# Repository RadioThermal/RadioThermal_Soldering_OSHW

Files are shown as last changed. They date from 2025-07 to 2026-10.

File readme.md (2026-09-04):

RadioThermal 470KHz Induction Soldering Station - Open Source Hardware
========================

This repository contains the designs and resources to build a high-performance induction soldering iron at a relatively low cost. [Check out radiothermal.com for more information.](https://radiothermal.com/products.html)

### [Join our Discord server](https://discord.gg/hySrP3z9Kq)

### [Join our mailing list to get updates on this project](https://radiothermal.com/mailing.html)

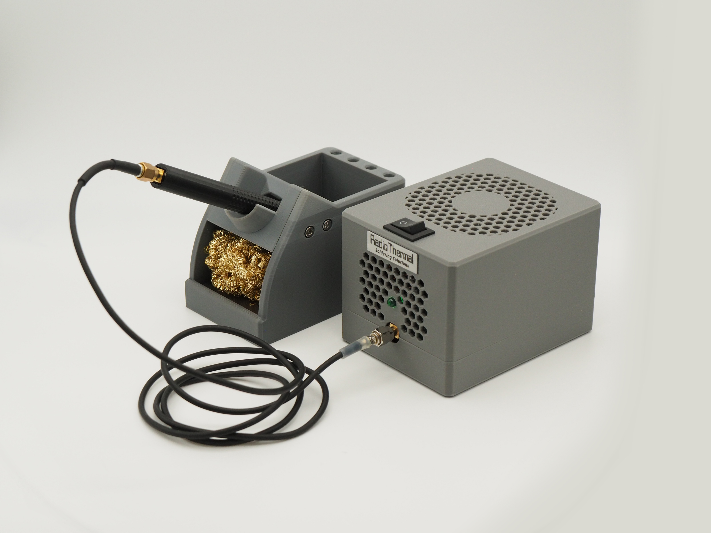
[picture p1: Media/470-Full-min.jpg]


The 470KHz soldering system is made up of four major components: the power supply, the handpiece, the cable, and the workstand. Follow the links to see the assembly instructions and files for each component.

### [Power Supply](https://github.com/RadioThermal/RadioThermal_Soldering_OSHW/tree/main/Power%20Supply)

The power supply is the core of the 470KHz system. It consists of a PCB design that includes a class-E amplifier and contains impedance matching circuitry to properly provide power to the soldering iron tip. 

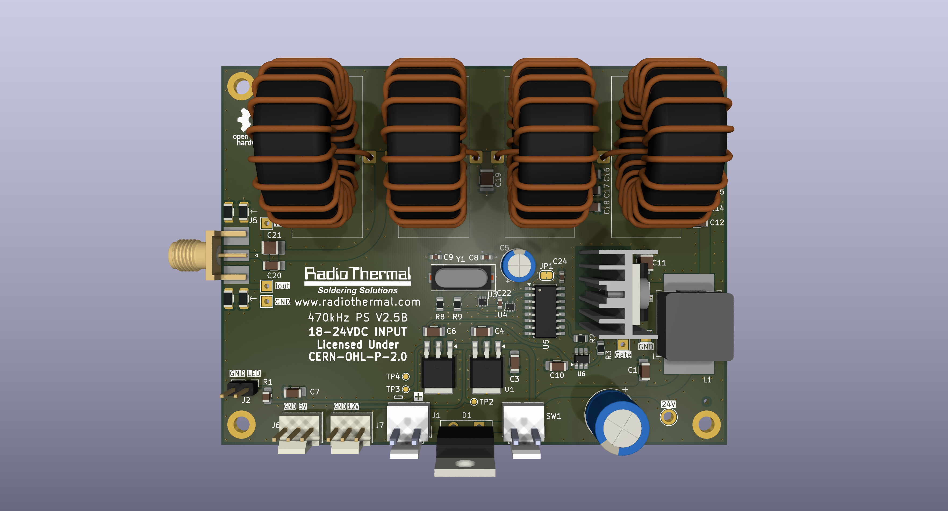
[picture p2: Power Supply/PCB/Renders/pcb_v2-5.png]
case


### [Handpiece](https://github.com/RadioThermal/RadioThermal_Soldering_OSHW/tree/main/Handpiece)

The handpiece is the primary user interface of the soldering system. It consists of a core built with brass tubing and an outer 3D printed grip for comfort during use.

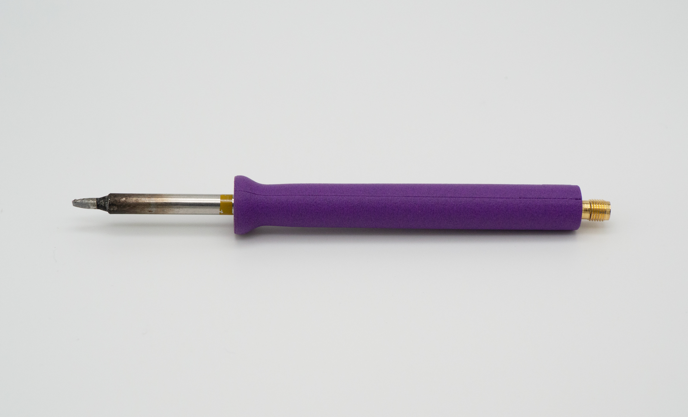
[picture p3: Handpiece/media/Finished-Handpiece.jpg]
hp


### [Cable](https://github.com/RadioThermal/RadioThermal_Soldering_OSHW/tree/main/Cable)

The cable is a specially modified RG-174 coaxial cable with SMA connectors on each end. A silicone jacket has been added for burn resistance, with additional silicone layers on each end for improved strain relief

### [Workstand](https://github.com/RadioThermal/RadioThermal_Soldering_OSHW/tree/main/Workstand)

The workstand is a primarly 3D printed part that gives the user a safe place to their hot soldering iron, along with brass wool to clean the tip. Magnets are used to cool down the soldering iron tip when not in use. The back of the stand contains storage for four tips.

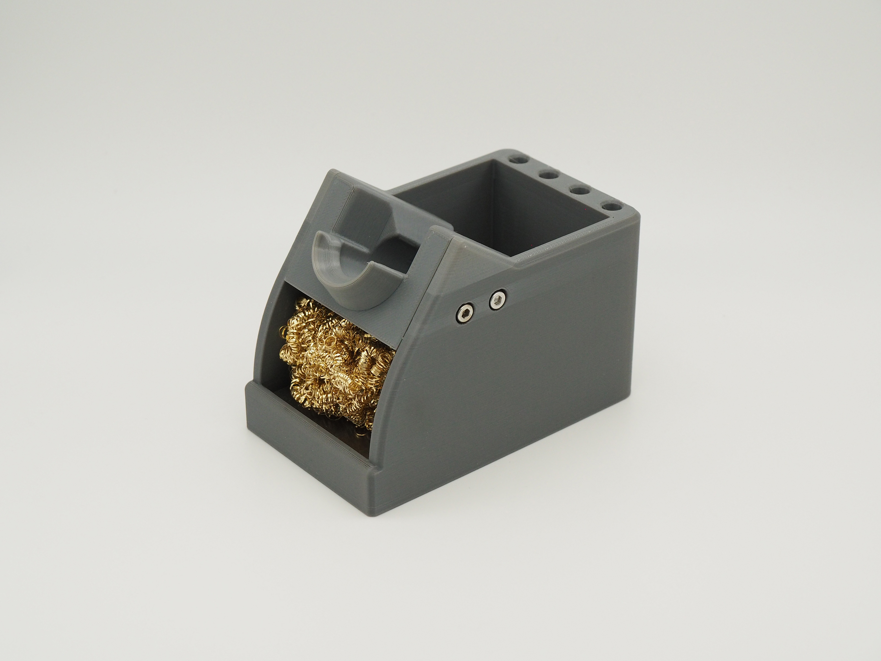
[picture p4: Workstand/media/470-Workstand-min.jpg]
ws


### [Extra - Compatibility Adapters](https://github.com/RadioThermal/RadioThermal_Soldering_OSHW/tree/main/Adapters)

We have designed compatibility adapters to allow our cable and handpiece to be used with preexisting 470KHz power supplies including Metcal PS, Metcal MFR, and Thermaltronics TMT-2000.

# Project Status

Here is an overview of the current state of completion for each major component of the project

| Component | Status |
| --- | --- |
| Power Supply | Updated to V2.5B |
| Handpiece | Complete |
| Cable | Complete |
| Workstand | Complete |
| Compatibility Adapters | Updated version coming soon |

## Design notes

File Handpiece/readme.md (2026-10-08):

# 470KHz Handpiece Assembly Instructions

#### 1. Gather materials

Prepare your materials for assembling the core of the handpiece. Links below go to where materials can be purchased.

| **Component** | **Quantity** | **Notes** |
| --- | --- | --- |
| Handpiece grip | 1 | 3D printed handpiece grip, in [3D Printed Grip folder](https://github.com/RadioThermal/RadioThermal_Soldering_OSHW/tree/main/Handpiece/3D%20Printed%20Grip) |
| [7/32" OD x 0.014" wall brass tube](https://ksmetals.com/products/round-brass-tube-7-32-od-x-0-014-wall-x-12-long-1-piece?) | 1 | Cut to 14mm length |
| [1/4" OD x 0.014" wall brass tube](https://ksmetals.com/products/br014-1-4?) | 1 | Cut to 70mm length |
| [Handpiece PCB](https://github.com/RadioThermal/RadioThermal_Soldering_OSHW/tree/main/Handpiece/Handpiece%20PCB) or Double sided copper clad FR4 board | 1 | For copper clad FR4 option, cut to 9x15mm rectangle |
| [Edge launch SMA connector](https://www.digikey.com/en/products/detail/samtec-inc/SMA-J-P-H-ST-EM1/2602450) | 1 | 7mm max width, straddle mount variety |
| [D-Sub female socket contact](https://www.digikey.com/en/products/detail/mh-connectors/MHDM-STF/16983882) | 1 | Solder cup variety, can be recycled from used connectors |
| 4.5mm OD x 8mm crown spring/socket contact | 1 | [Aliexpress](https://www.aliexpress.us/item/3256801561640843.html?) (contact seller for more size options), [TE Connectivity](https://www.te.com/en/product-6-192041-9.html), or [DigiKey](https://www.digikey.com/short/35073bvt) |
| 470KHz soldering iron tip | 1 | [Metcal/OKi STP/SFP/SCP series](https://store.metcal.com/en-us/shop/cartridges-tips/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) tips or [Thermaltronics P series](https://www.thermaltronics.com/p_series.php) tips |

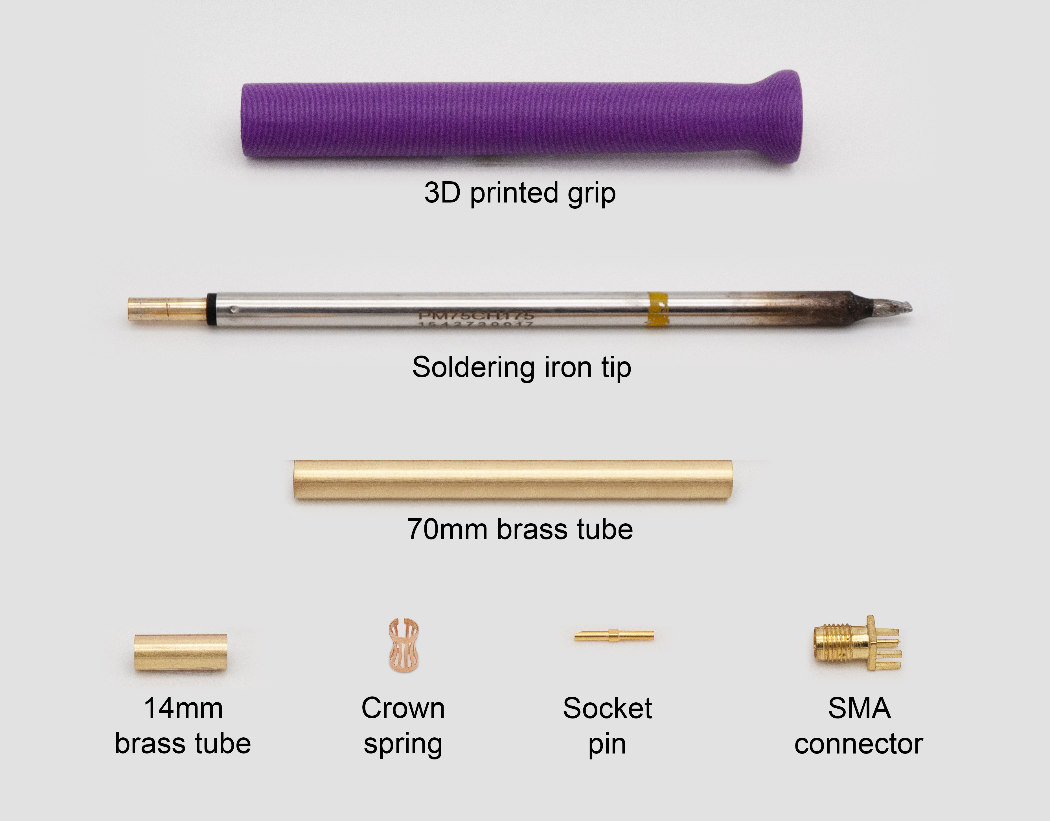
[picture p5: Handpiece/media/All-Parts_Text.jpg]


#### 2. Prepare circuit board

**Tools and components needed:**

If using premade [Handpiece PCB](https://github.com/RadioThermal/RadioThermal_Soldering_OSHW/tree/main/Handpiece/Handpiece%20PCB), skip to step 3

| Component | Quantity |
| --- | --- |
| Double sided copper clad FR4 board | 1 |

| Tool | Description/use |
| --- | --- |
| Hacksaw | Cutting FR4 |
| Vise or clamp | Holding FR4 during cutting |
| Calipers | Measuring FR4 |
| Narrow chisel | Cutting FR4 and scraping copper |
| Rectangular metal file | Flattening FR4 edges, cleaning up cuts |
| Fine point permanent marker | Marking FR4 for cutting and copper for scraping |

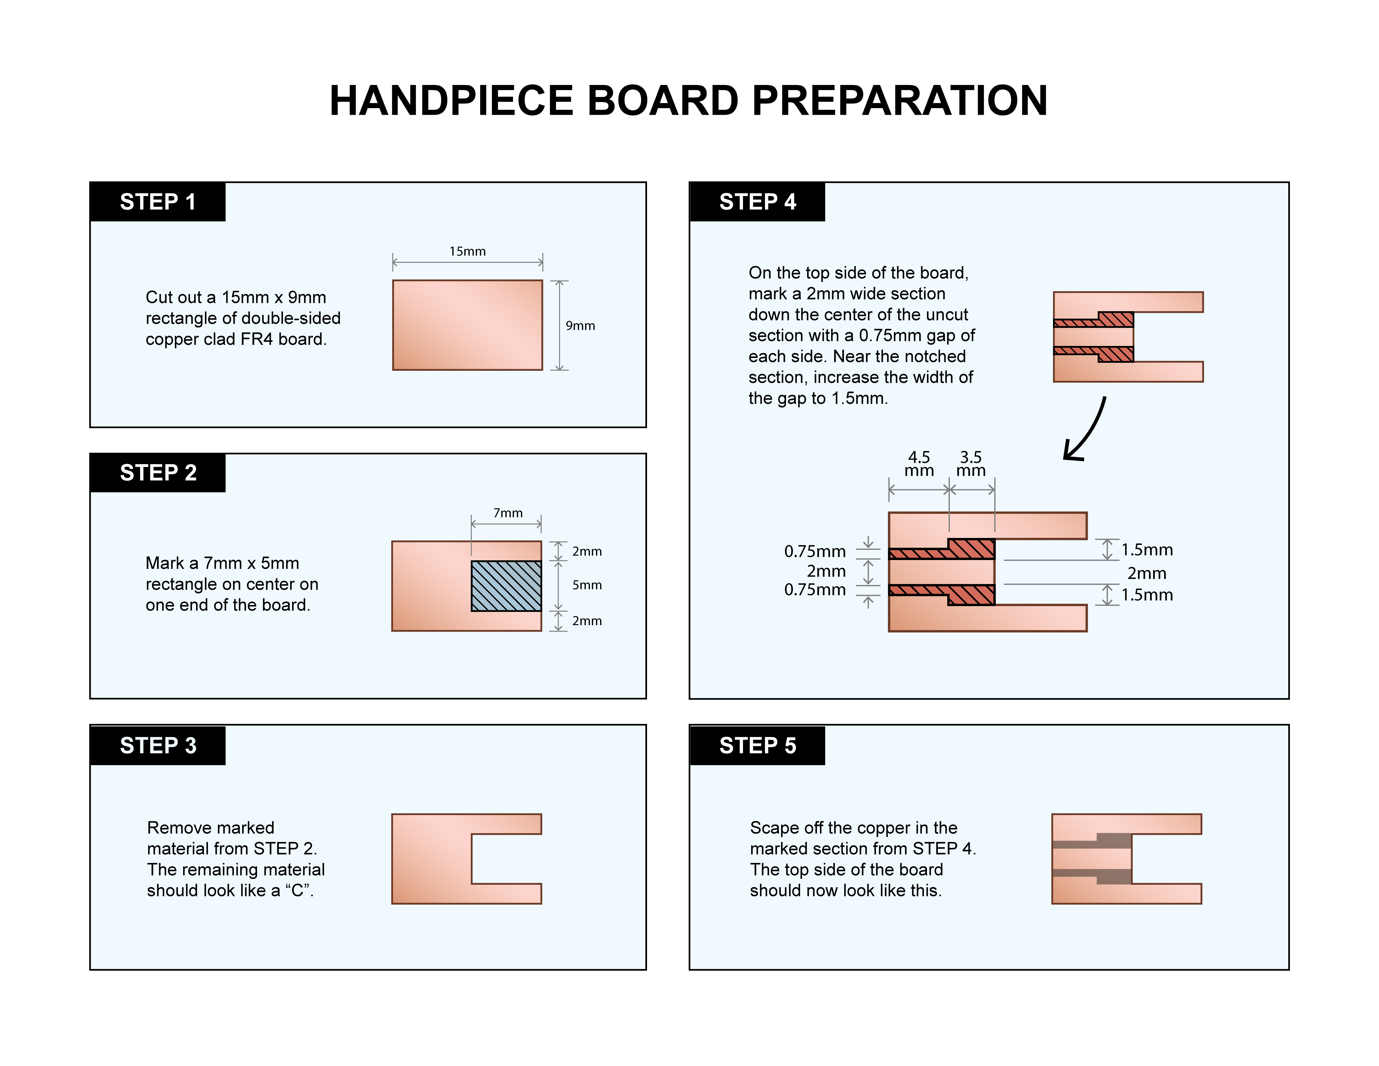
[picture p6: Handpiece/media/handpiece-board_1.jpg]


#### 3. Attach the SMA connector

**Tools and components needed:**

| Component | Quantity |
| --- | --- |
| Completed 9x15mm board with notch cut and copper removed | 1 |
| Edge launch SMA connector | 1 |

| Tool | Description/use |
| --- | --- |
| Soldering iron | Soldering SMA connector to board |
| Solder | 63/37 alloy is peferable, other leaded or lead free alloys may work |
| Flux | Liquid type is preferable |
| Needle nose pliers | Bending SMA connector legs |

Once the board has been completed, now it is time to attach the SMA connector. Position the connector so that the center contact touches the 2mm wide center strip on the board, while the outer legs do not touch the center strip. If the connector is a loose fit on the board, bend the outer legs together slightly so that it securely grasps the board. 

Apply soldering flux to all of the legs of the SMA connector. Starting from the outer legs, solder the connector to the board. When soldering the center pin, do not keep the soldering iron on the pin for an extended period of time, as it may damage the plastic insulator inside the connector. Once soldering of the SMA connector is complete, inspect and correct any solder bridges between the center pin and outer legs.



#### 4. Install crown spring into socket tube

**Tools and components needed:**

| Component | Quantity |
| --- | --- |
| 4.5x8mm crown spring | 1 |
| 7/32" OD x 0.014" wall brass tube, cut to 14mm | 1 |
| 470KHz soldering iron tip | 1 |

| Tool | Description/use |
| --- | --- |
| Soldering iron | Soldering crown spring into tube |
| Solder | 63/37 alloy is preferable, other leaded or lead free alloys may work |
| Flux | Liquid type is preferable |



Insert the crown spring into the 14mm piece of brass tubing, then partially insert the coaxial end of the soldering iron tip into the crown spring. Leave about half of the spring visible and ensure there is a 2mm space between the top of the spring and the end of the tubing.



Once the spring has been placed, apply a small amount of liquid soldering flux to the exposed end of the spring. Using a fine tip soldering iron, apply a small amount of solder to where the spring contacts the brass tube. Make sure the solder flows around the spring  to ensure that it says in place during use.

#### 5. Complete the socket assembly

**Tools and components needed:**

| Component | Quantity |
| --- | --- |
| Board with SMA connector from step 3 | 1 |
| 14mm socket tube with spring from step 4 | 1 |
| D-Sub female socket contact | 1 |
| 470KHz soldering iron tip | 1 |

| Tool | Description/use |
| --- | --- |
| Soldering iron | Soldering tube and socket pin to board |
| Solder | 63/37 alloy is preferable, other leaded or lead free alloys may work |
| Flux | Liquid type is preferable |



Begin by inserting the D-Sub female socket contact onto the center pin of the coaxial connector of the soldering iron tip. Verify that the contact is able to easily slide onto the center pin and grasps firmly enough to not fall off when turned upside down. If the contact is loose on the center pin, it may be necessary to squeeze the cut end slightly so that it firmly grasps the pin. Once the socket contact has been fully inserted, slide it approximately 2mm back off of the pin so that it can account for variances in soldering iron tip connectors.

Next, slide the 14mm socket tube all the way down on the outer ring of the coaxial connector on the soldering iron tip. The soldered end of the spring should be facing outwards.



Slide the notched section of the board all of the way onto the socket tube, and ensure the center pin is aligned with the 2mm copper strip.

Apply flux to the points of contact between the socket tube and the board. Solder the socket tube to the board. Make sure that the solder flows onto both the tubing and board, creating a strong bond. It is only necessary to solder on the top side of the board. Be careful not to keep the soldering iron on the board and tubing for an extended period of time. Excessive heat could cause the previously soldered components to lose their connection. Finally, solder the D-Sub female contact onto the 2mm strip on the board.



Now the socket assembly is complete. Clean off any remaining flux. Test the socket assembly using a multimeter in continuity mode with probes connected to the center pin and outside of the SMA connector. If no soldering iron tip is inserted, the connection will be open. If a tip is inserted, the connection will be shorted.



#### 6. Attach the support tube to the socket assembly

**Tools and components needed:**

| Component | Quantity |
| --- | --- |
| Socket assembly from step 5 | 1 |
| 11/4" OD x 0.014" wall brass tube, cut to 70mm | 1 |
| 470KHz soldering iron tip | 1 |

| Tool | Description/use |
| --- | --- |
| Soldering iron | Soldering tube and socket pin to board |
| Solder | 63/37 alloy is preferable, other leaded or lead free alloys may work |
| Flux | Liquid type is preferable |
| Isopropyl alcohol | Removing flux residue |



Slide the 70mm piece of tubing onto the coaxial connector end of the soldering iron tip. Ensure that the tube is slid past the end of the coaxial connector section of the tip. The tubing should be able to slide onto the tip very easily. If the tubing does not slide easily, replace your tubing.

Next, slide the socket assembly fully onto the coaxial connector of the soldering iron tip. Slide the 70mm tube back so that it is covering the first 3mm of the tube in the socket assembly. Use a piece of kapton tape to affix the 70mm tube to the soldering iron tip so that it does not move during the soldering process.

Apply soldering flux to the where the brass tubes contact. Apply a small amount of solder to the joint between the two tubes and rotate the workpiece so that the entirety of the joint between the brass tubes is soldered. Make sure that the solder flows onto both pieces of tubing, creating a strong bond. Finally, remove the kapton tape and soldering iron tip.

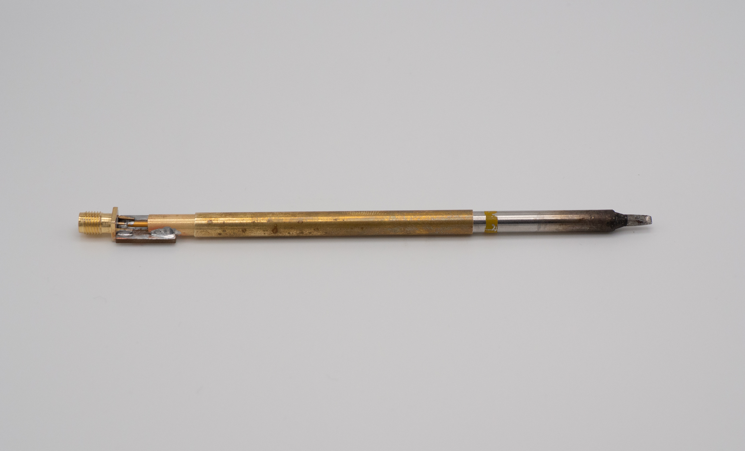
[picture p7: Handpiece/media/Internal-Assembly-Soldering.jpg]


The inner portion of the handpiece is complete. Clean off any remaining flux and thoroughly wash the inside of the tube with isopropyl alcohol or another solvent. Test the fit of the tip into the assembly. It should easily slide into the tube and firmly grasp once it reaches the socket. 



#### 7. Installing the handpiece grip

**Tools and components needed:**

| Component | Quantity |
| --- | --- |
| Handpiece innner assembly from step 6 | 1 |
| 3D printed handpiece grip | 1 |

| Tool | Description/use |
| --- | --- |
| 1/4" drill bit | Removing stringing and widening grip |



Inspect the 3D printed handpiece grip to verify that there is no stringing inside the hole. If stringing is present, use a 1/4" drill bit to clear the hole. Next, insert the inner assembly into the 3D printed grip. It should be a tight fit. If the inner assembly cannot be inserted, use a 1/4" drill bit to enlarge the hole. The inner assembly is fully inserted when only the SMA connector is protruding from the grip.

Now your 470KHz handpiece is complete!



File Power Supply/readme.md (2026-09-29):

# Power Supply

The power supply is the core of the 470KHz system. It is based upon a class-E amplifier and contains impedance matching circuitry to properly provide power to the soldering iron tip.

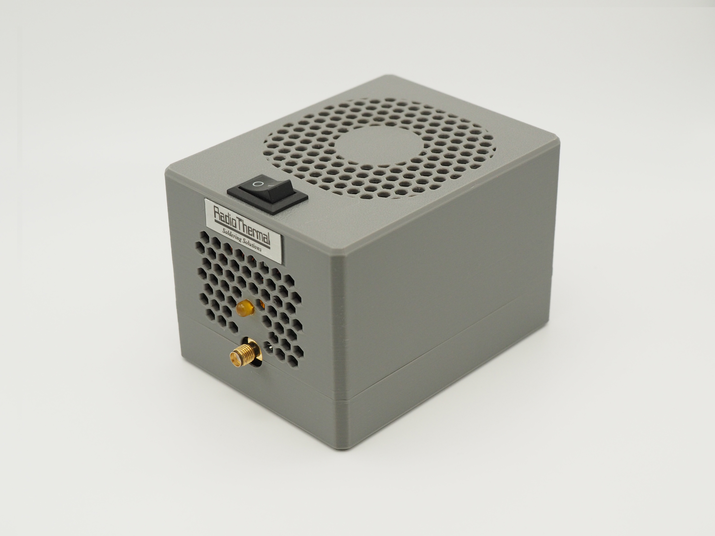
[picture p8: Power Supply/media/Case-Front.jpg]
(/media )


#### The PCB

The provided PCB design includes all basic functionality needed to operate a 470KHz soldering iron tip. 

The design includes provisions for inrush current limiting, reverse polarity protection, a cooling fan, and two different types of oscillators. The inductors, apart from the fixed 33uH inductor, are all based around the [Kool Mu 0077932A7 core](https://www.mag-inc.com/Media/Magnetics/Datasheets/0077932A7.pdf), which is currently only available from Digikey, though we are looking for alternatives. 

In version 2.5B of the PCB, we have made a few improvements to reduce cost and increase reliability compared with version 2.3B1. Most notably the oscillator section has been redesigned to eliminate the need for a microcontroller and now only relies on a 7.6MHz crystal oscillator and TTL logic. To reduce costs, we have eliminated the daughter board by moving everything onto the main board, additionally L2 has been updated to only use a single inductor core from the two cores required on previous versions. Moving all of this new hardware onto the main board has had the consequence of causing us to remove the TO-247 MOSFET option in favor of TO-220 to save space.



Components required to assemble the board can be found in the [Digikey list we maintain](https://www.digikey.com/en/mylists/list/PVYU6ZC8DQ) , please let us know if there is a stocking issue for a component so that we can find a suitable alternative.

**Special note:** if you are one of the few people with a **V2.5** non-B PCB, please replace the 74LVC1G14 with a [74LVC2G14](https://www.digikey.com/en/products/detail/nexperia-usa-inc/74LVC2G14GW-125/1231583)

#### External DC Power Supplies

For testing we have been using Chicony A15-180P1A 20V 180W power supplies, however any power supply in the 18-24V range with a 100W or higher rating will work. We recommend utilizing a laptop power supply since they can be found on the used market at reasonable prices. Alternatively, a USB-C PD trigger board can be used in conjunction with a USB PD power supply that supports 20V 5A output.

#### The Case

The case design adds additional functionality to the PCB including a barrel jack for power input, a convenient power switch, power indicator LED, cooling fan, and a ground connection point. The airflow paths of the case have been optimized to exhaust out the front and back with the intake on top, keeping all of the inductors cool.

a

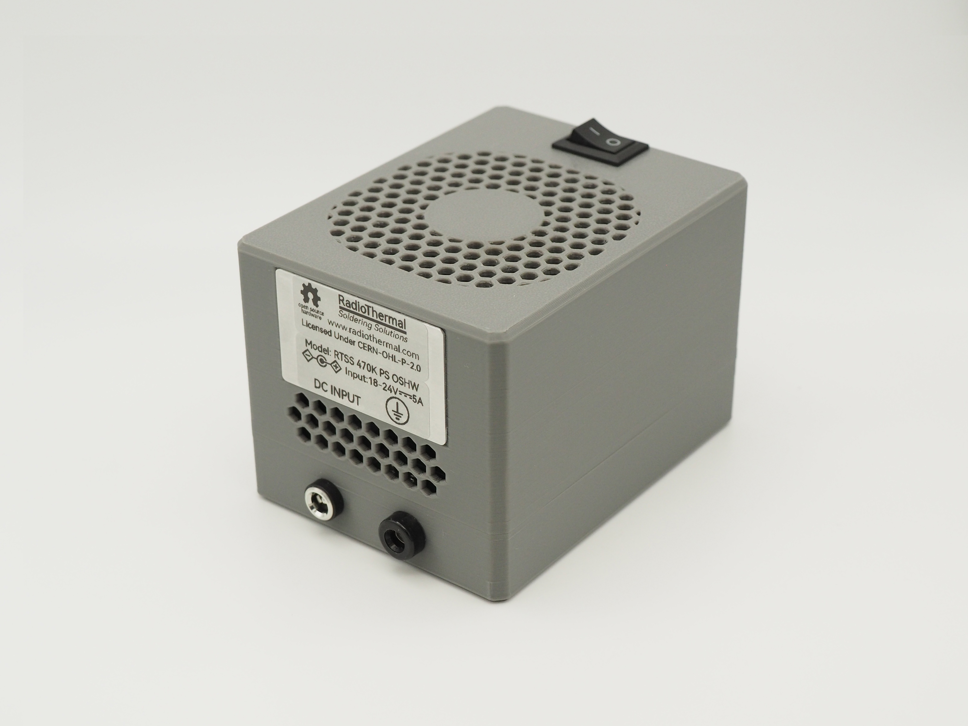
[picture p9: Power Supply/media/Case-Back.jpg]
case


The electronics parts and fasteners for the case [can be purchased from Digikey](https://www.digikey.com/en/mylists/list/RQ7FUDUM3L). 

The case fan mounts are only designed to support Delta AFB0712 series fans at present, other 70mm fans can be used by removing the fan mounting posts and gluing the four corners of the fan in place.

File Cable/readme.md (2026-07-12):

# Cable Assembly Instructions

#### 1. Gather materials

Prepare the following materials to assemble the cable

| **Component** | **Quantity** | **notes** |
| --- | --- | --- |
| RG174 coaxial cable | 1 | Cut to 1-2m length, depending on how long ou want your cable to be. For best results, use a cable with a tight braid and high flexibility. MUST have a full braided shield—some chinese wire will not. |
| [Male SMA connector, inline](https://www.digikey.com/en/products/detail/adam-tech/RF2-02B-T-02-50-G/9831397) | 2 |  |
| 3mm ID silicone heatshrink tubing | 1 | Cut to the same length as your coax |
| 3mm ID silicone heatshrink tubing | 2 | Cut to 2mm length |
| 5mm ID silicone heatshrink tubing | 2 | Cut to 70mm length |
| 6mm ID heatshrink tubing | 2 | Cut to 40mm length |

#### 2. Deglove the coax

Take a sharp cutting implement and make a vertical incision about 3cm long at one end of the coax jacket. Grab the jacket in one hand and the internal coax cable in the other hand, and pull/rip the coax down through the incision in the jacket. Removing the jacket increases the flexibility and decreases the weight of the cable.

#### 3. Install the silicone heatshrink tube

Heat one end of the coax with a soldering iron, pushing the shield into the dielectric for about 5mm from the end. Depending on the coax core material, this may not work and you will instead need to solder the very front of the coax. This is necessary to keep the shield from catching and getting stuck while feeding the coax through the heatshrink.

Apply an aligator clip to the end that is not soldered to prevent the shield from shifting.

Lightly lubricate the coax and the lubricate the inside of the silicone heatshrink with any liquid lubricant. Even mineral oil or WD40 will work fine here. I'd caution against using water, because it might cause corrosion, or vegetable oil, because it can gum up over time.

Feed the coax through the silicone heatshrink. When it becomes difficult to feed, inch it along by doing the following:
Pinch and hold the end of the coax through the heatshrink
Stretch the heatshrink a few centimeters toward the loose end
Pinch and hold the coax through the heatshrink at the end of the stretched section
Release the end of the coax and it should be pushed foward by the contracting heatshrink.

When the coax is completely though, apply alligator clips to each end to prevent shifting within the heatshrink.

#### 4. Prepare strain relief

Slide the strain relief heatshrink sections into the center of the cable in the proper order: 6mm, then 5mm.

#### 5. Install the SMA connectors

Pull back the silicone heatshrink about 3cm and re-secure it with the alligator clip.
Slide a 2mm section of the 3mm ID heatshrink onto the cable (this provides a smooth transistion for strain relief purposes) 
Slide the crimp ferrule onto the coax and up to the jacket.
Cut off the melted/soldered section of the coax.

The following instructions depend on the type of SMA connector you have. We have instructions for two common types from aliexpress.

### Connector type 1
**include image of connector type 1 here**
Use a blade or sharp snips to remove 5mm of the coax shield without cutting the dielectric.
Pull back the coax shield at least 1cm.
Strip 2mm of dielectric from the inner conductor.
Solder the inner SMA pin onto the inner conductor of the coax. You may need to use a blade to trim the melted dielectric to fit it in the SMA body.

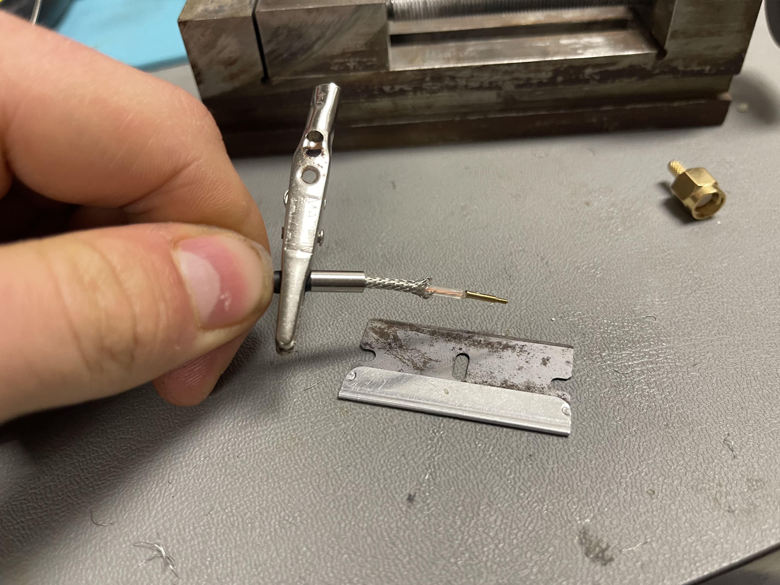
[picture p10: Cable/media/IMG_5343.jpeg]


Slide the inner SMA pin into the SMA body, moving the coax shield forward to cover the knurled crimp area.
Slide the crimp ferrule over the coax shield to completely cover the knurled crimp area. This may require some force. Use a blade to trim any strands of coax shield that are sticking out.

Crimp or solder the ferrule onto the base of the SMA connector. Soldering is strongly recommended if you don't have the correct size hex crimp tool.

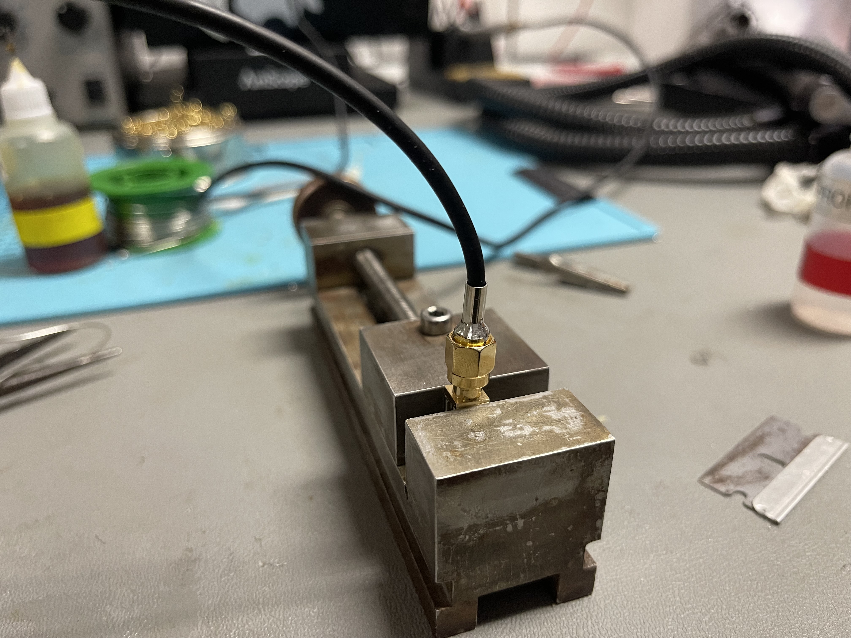
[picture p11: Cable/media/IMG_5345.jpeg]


### Connector type 2
**include image of connector type 2 here**
Use a blade or sharp snips to remove 2mm of the coax shield and dielectric to leave just the inner conductor.
Pull back the coax shield at least 1cm.
Solder the inner conductor of the coax to the inner SMA pin.

IMAGE!

Move the coax shield forward to cover the thinner knurled crimp area. Trim any stray wires that go onto the larger knurled area.
Slide the crimp ferrule over the coax shield to completely cover the solder access hole and be flush with the SMA connector.

Crimp or solder the ferrule onto the SMA connector. Soldering is strongly recommended if you don't have the correct size hex crimp tool.

IMAGE!

#### 6. Install the strain relief

Slide the 2mm long section of 3mm ID heatshrink against the crimp ferrule and shrink it in place.

Release the 3mm heatshrink jacket from its aligator clip and slide it over the 2mm long section and the ferrule. This may require lubrication. If the connector is Type 2, only slide the jacket over the smaller section.

Shrink the silcone jacket.

Wait for the cable to cool, then slide the piece of 5mm ID heatshrink tubing over the ferrule, as close to the SMA connector as it will go.
While pushing on the end away from the SMA, use hot air to heat the end next to the SMA until it stops shrinking. Then stop pushing and heat the rest of the 5mm heatshrink.
Wait for the cable to cool, then repeat with the 6mm ID heatshrink.

#### 7. Repeat steps 5 and 6 on the other end of the cable.

Now your silicone SMA cable is complete!

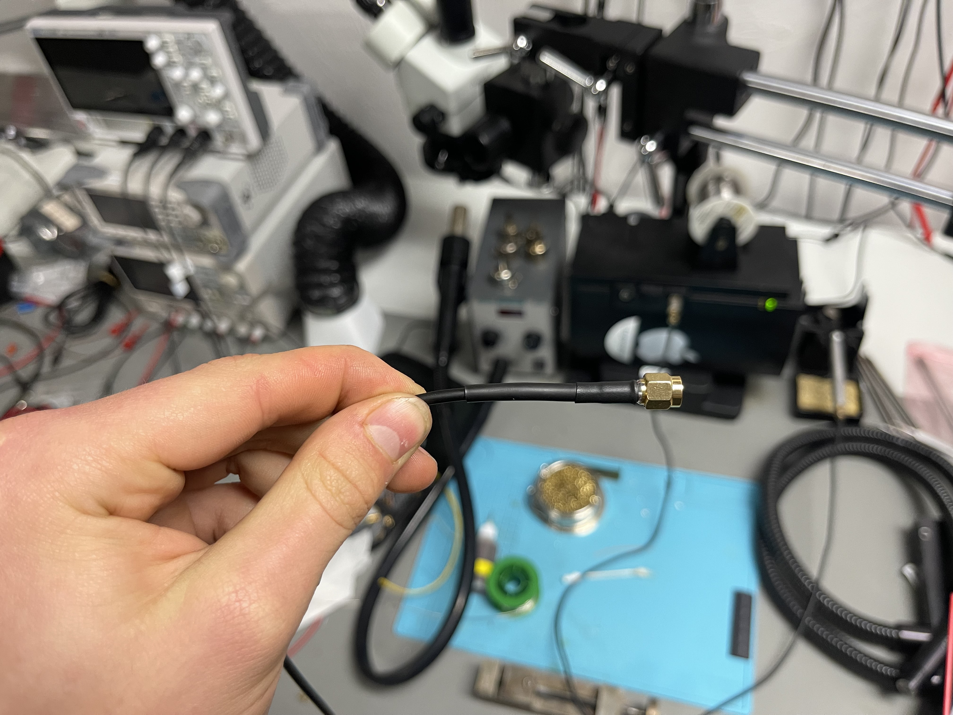
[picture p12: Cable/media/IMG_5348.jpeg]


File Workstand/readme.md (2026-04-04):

## Workstand Assembly Instructions



#### 1. Gather materials

Prepare your materials for assembling the workstand. Links below go to where materials can be purchased.

| **Component** | **Quantity** | **Notes** |
| --- | --- | --- |
| Workstand base | 1 | 3D printed workstand base, in [3D Printed Parts folder](https://github.com/RadioThermal/RadioThermal_Soldering_OSHW/Workstand/3D_Printed_Parts) |
| Workstand insert | 1 | 3D printed workstand insert, in [3D Printed Parts folder](https://github.com/RadioThermal/RadioThermal_Soldering_OSHW/Workstand/3D_Printed_Parts) |
| 3/8th" steel plate | 1 | Weight for the stand, cut to 90x50mm |
| 12x3mm round N52 magnets | 8 | Enables tip sleep functionality, not required |
| M3x8 socket cap bolts | 4 | M3x10 plastite screws can be used as well |
| Aluminum tape (155x50mm total) | 1 | Provides heat reistance to 3D prtinted parts, cut two 40x50mm pieces, one 55x50mm piece, and one 20x50mm piece |
| Brass wool | 1 | |
| Self adhesive rubber feet | 4 | Optional |

#### 2. Assemble workstand insert

**Components needed:**

| Component | Quantity |
| --- | --- |
| 3D printed workstand insert | 1 |
| 12x3mm round N52 magnets | 8 |
| 20x50mm aluminum tape | 1 |

Start by applying the aluminum tape to the flat area on the underside of the 3d printed part. Next seperate the magnets into two stacks of four and note the polarity of each. place each stack of magnets in the cavity on each side of the insert with the same polarity facing towards the center of the tip holder so that each stack of magents repels the other. Affix the magents to the stand with hot glue. 

#### 3. Assemble workstand base

**Components needed:**

| Component | Quantity |
| --- | --- |
| 3D printed workstand base | 1 |
| Self adhesive rubber feet | 4 |
| 40x50mm aluminum tape | 2 |
| 55x50mm aluminum tape | 1 |
| 90x50mm 3/8" steel plate  | 1 |

Begin by flipping the workstand base over and apply the rubber feet to the 4 indicated locations. Back on the top side, apply the two smaller pieces of aluminum tape to each of the inside side walls, directly behind the lower curved section on the front. Next, apply the larger piece of aluminum tape to rear inside wall. Finally, drop in the steel plate, if needed it can be attached to the base with double sided tape or glue.

#### 4. Final assembly

**Components needed:**

| Component | Quantity |
| --- | --- |
| Workstand insert from step 2 | 1 |
| Workstand base from step 3 | 1 |
| M3x8 socket cap bolts | 4 |
| Brass wool | 1 |

Begin by taking the base and insert, and aligning the four mounting holes then using the four bolts to attach the insert to the base. Finally the brass wool can be inserted into the area beneath the insert.

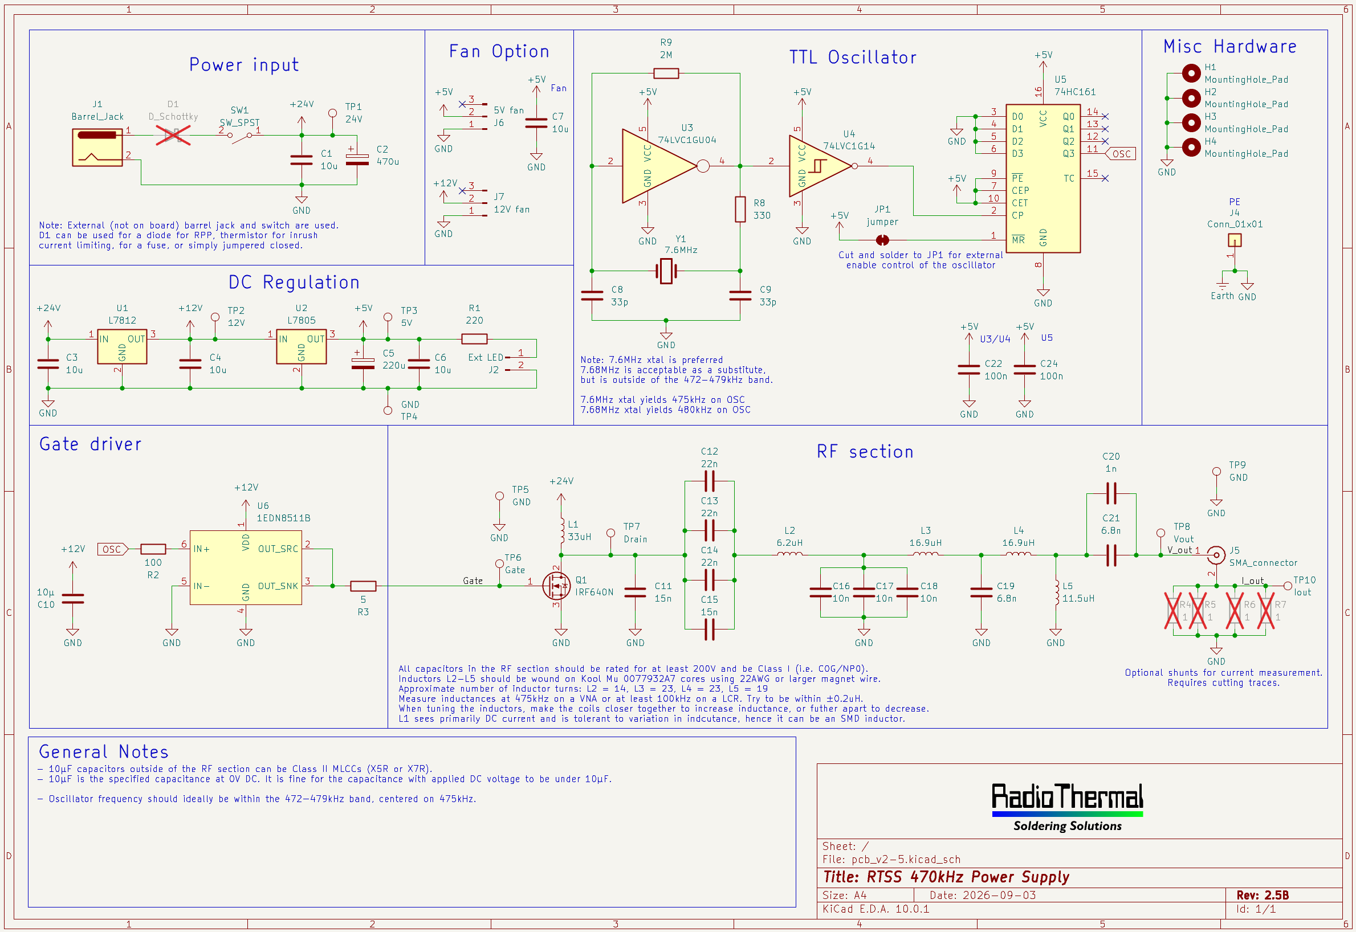
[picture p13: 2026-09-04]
Power Supply/PCB/Renders/pcb_v2-5_schematic.png

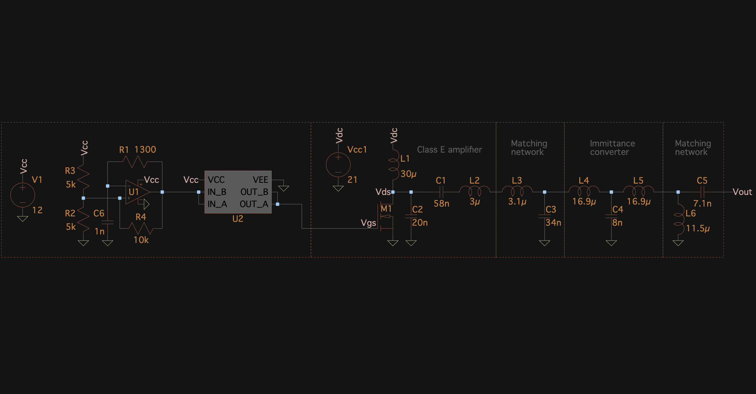
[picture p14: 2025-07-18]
Power Supply/media/schematic.png

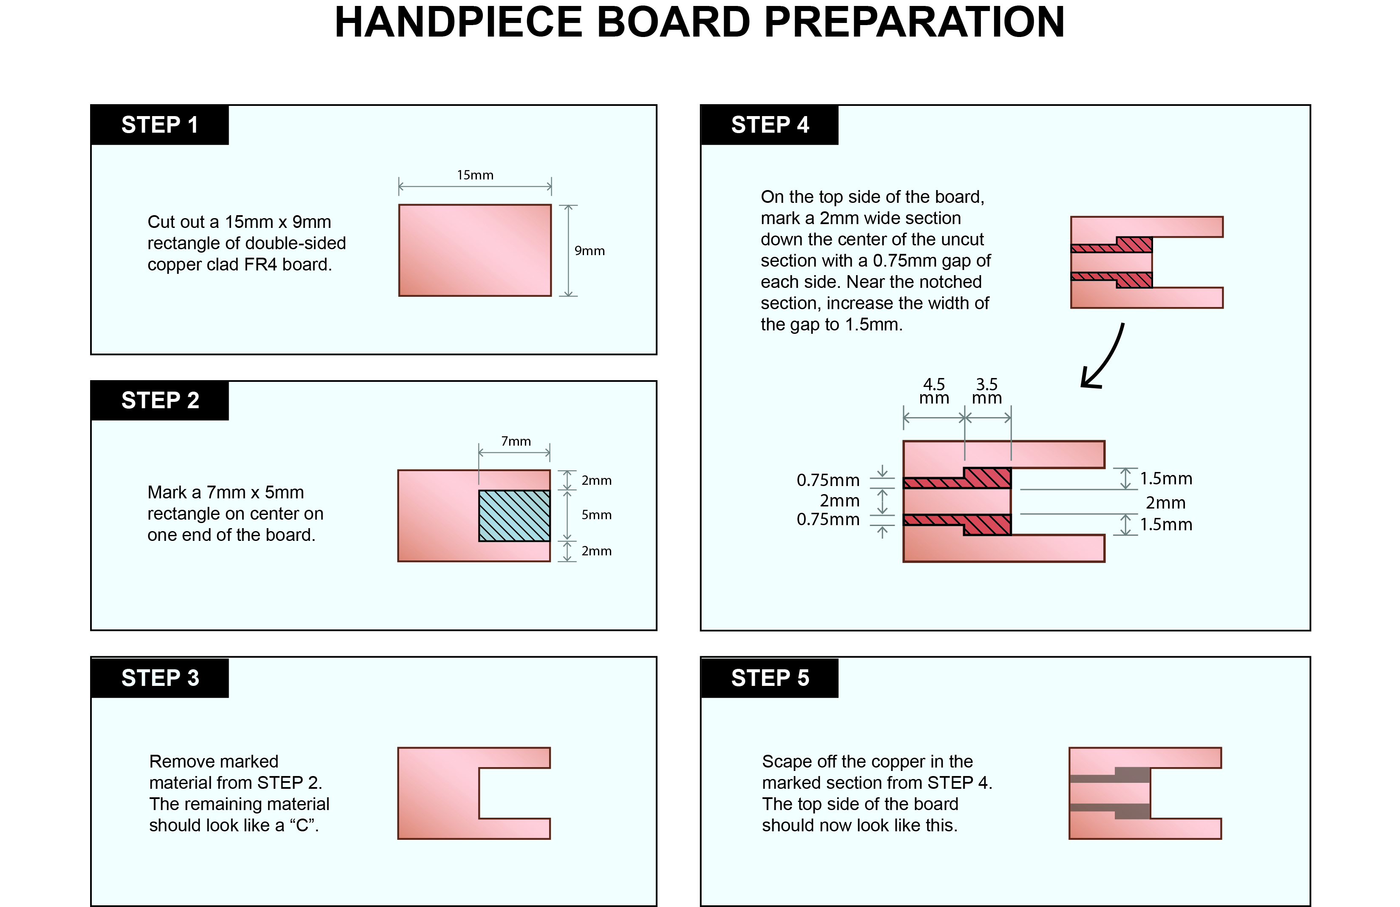
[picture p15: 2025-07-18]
Handpiece/media/handpiece-board.jpg

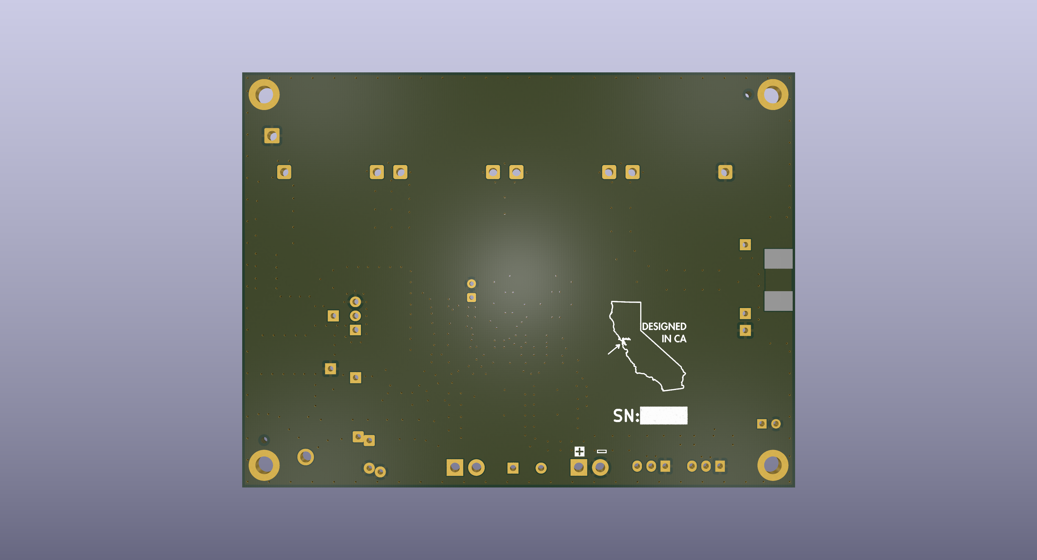
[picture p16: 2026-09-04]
Power Supply/PCB/Renders/pcb_v2-5_bottom.png

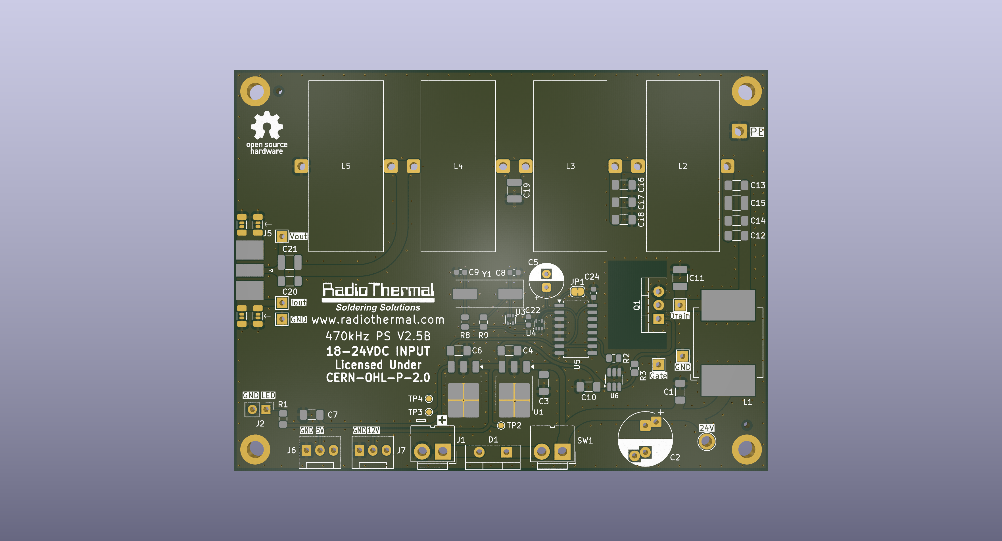
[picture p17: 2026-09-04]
Power Supply/PCB/Renders/pcb_v2-5_top.png

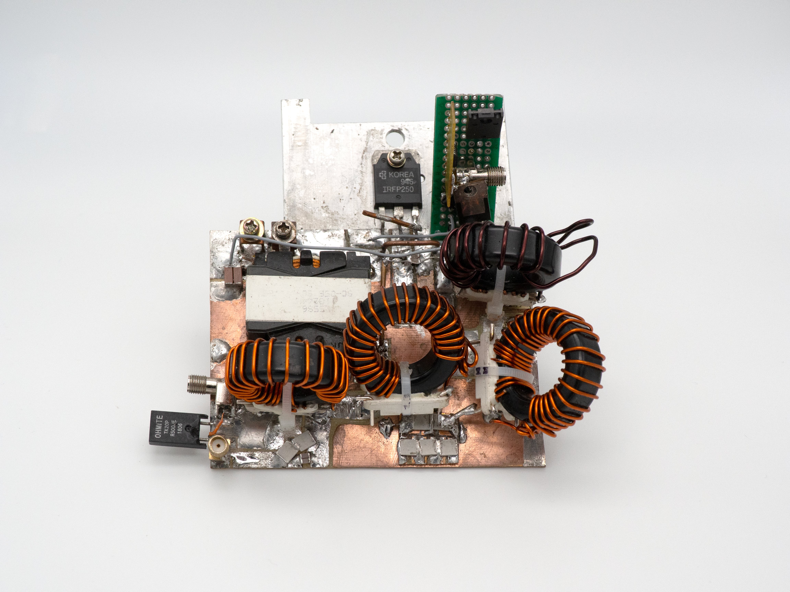
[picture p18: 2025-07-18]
Power Supply/media/470-Powersupply-min.jpg

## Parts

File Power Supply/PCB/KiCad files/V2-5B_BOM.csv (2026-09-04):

Reference | Qty | Value | DNP | Exclude from BOM | Exclude from Board | Footprint | Datasheet
C1,C3,C4,C6,C7 | 5 | 10u |  |  |  | Capacitor_SMD:C_1206_3216Metric_Pad1.33x1.80mm_HandSolder
C2 | 1 | 470u |  |  |  | Capacitor_THT:CP_Radial_D10.0mm_P5.00mm_P7.50mm
C5 | 1 | 220u |  |  |  | Capacitor_THT:CP_Radial_D6.3mm_P2.50mm
C8,C9 | 2 | 33p |  |  |  | Capacitor_SMD:C_0603_1608Metric
C10 | 1 | 10µ |  |  |  | Capacitor_SMD:C_1206_3216Metric_Pad1.33x1.80mm_HandSolder
C11,C15 | 2 | 15n |  |  |  | Capacitor_SMD:C_1210_3225Metric_Pad1.33x2.70mm_HandSolder
C12,C13,C14 | 3 | 22n |  |  |  | Capacitor_SMD:C_1206_3216Metric_Pad1.33x1.80mm_HandSolder
C16,C17,C18 | 3 | 10n |  |  |  | Capacitor_SMD:C_1206_3216Metric_Pad1.33x1.80mm_HandSolder
C19,C21 | 2 | 6.8n |  |  |  | Capacitor_SMD:C_1210_3225Metric_Pad1.33x2.70mm_HandSolder
C20 | 1 | 1n |  |  |  | Capacitor_SMD:C_1206_3216Metric_Pad1.33x1.80mm_HandSolder
C22,C24 | 2 | 100n |  |  |  | Capacitor_SMD:C_0603_1608Metric
J1 | 1 | Barrel_Jack |  |  |  | custom_parts:3D-JWT_A3963_1x02_P3.96mm_Vertical
J2 | 1 | Ext LED |  |  |  | Connector_PinHeader_2.54mm:PinHeader_1x02_P2.54mm_Vertical
J5 | 1 | SMA_connector |  |  |  | custom_parts:SMA_EdgeMount_Horizontal
J6 | 1 | 5V fan |  |  |  | Connector:FanPinHeader_1x03_P2.54mm_Vertical
J7 | 1 | 12V fan |  |  |  | Connector:FanPinHeader_1x03_P2.54mm_Vertical
L1 | 1 | 33uH |  |  |  | custom_parts:L_Pulse_PA4343
L2 | 1 | 6.2uH |  |  |  | custom_parts:L_Koolmu_1x_small_THTonly_0077932A7
L3,L4 | 2 | 16.9uH |  |  |  | custom_parts:L_Koolmu_1x_small_THTonly_0077932A7
L5 | 1 | 11.5uH |  |  |  | custom_parts:L_Koolmu_1x_small_THTonly_0077932A7
Q1 | 1 | IRF640N |  |  |  | custom_parts:3D_TO-220-3_Vertical | https://www.infineon.com/assets/row/public/documents/24/49/infineon-irfb4615-datasheet-en.pdf
R1 | 1 | 220 |  |  |  | Capacitor_SMD:C_0805_2012Metric_Pad1.18x1.45mm_HandSolder
R2 | 1 | 100 |  |  |  | Resistor_SMD:R_0805_2012Metric
R3 | 1 | 5 |  |  |  | custom_parts:Bridge_R_0805_2012Metric
R8 | 1 | 330 |  |  |  | Resistor_SMD:R_0805_2012Metric
R9 | 1 | 2M |  |  |  | Resistor_SMD:R_0805_2012Metric
SW1 | 1 | SW_SPST |  |  |  | custom_parts:3D-JWT_A3963_1x02_P3.96mm_Vertical
TP1 | 1 | 24V |  |  |  | TestPoint:TestPoint_Plated_Hole_D2.0mm
TP2 | 1 | 12V |  |  |  | TestPoint:TestPoint_Pad_D1.0mm
TP3 | 1 | 5V |  |  |  | TestPoint:TestPoint_Pad_D1.0mm
TP4 | 1 | GND |  |  |  | TestPoint:TestPoint_Pad_D1.0mm
TP5,TP9 | 2 | GND |  |  |  | TestPoint:TestPoint_THTPad_2.0x2.0mm_Drill1.0mm
TP6 | 1 | Gate |  |  |  | TestPoint:TestPoint_THTPad_2.0x2.0mm_Drill1.0mm
TP7 | 1 | Drain |  |  |  | TestPoint:TestPoint_THTPad_2.0x2.0mm_Drill1.0mm
TP8 | 1 | Vout |  |  |  | TestPoint:TestPoint_THTPad_2.0x2.0mm_Drill1.0mm
TP10 | 1 | Iout |  |  |  | TestPoint:TestPoint_THTPad_2.0x2.0mm_Drill1.0mm
U1 | 1 | L7812 |  |  |  | Package_TO_SOT_SMD:TO-252-3_TabPin2 | http://www.st.com/content/ccc/resource/technical/document/datasheet/41/4f/b3/b0/12/d4/47/88/CD00000444.pdf/files/CD00000444.pdf/jcr:content/translations/en.CD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
U2 | 1 | L7805 |  |  |  | Package_TO_SOT_SMD:TO-252-3_TabPin2 | http://www.st.com/content/ccc/resource/technical/document/datasheet/41/4f/b3/b0/12/d4/47/88/CD00000444.pdf/files/CD00000444.pdf/jcr:content/translations/en.CD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
U3 | 1 | 74LVC1GU04 |  |  |  | Package_TO_SOT_SMD:SOT-553 | http://www.ti.com/lit/ds/symlink/sn74lvc1gu04.pdf
U4 | 1 | 74LVC1G14 |  |  |  | Package_TO_SOT_SMD:SOT-553 | https://www.ti.com/lit/ds/symlink/sn74lvc1g14.pdf
U5 | 1 | 74HC161 |  |  |  | Package_SO:SOP-16_4.4x10.4mm_P1.27mm | http://www.ti.com/lit/gpn/sn74LS161
U6 | 1 | 1EDN8511B |  |  |  | Package_TO_SOT_SMD:SOT-23-6_Handsoldering
Y1 | 1 | 7.6MHz |  |  |  | Crystal:Crystal_SMD_HC49-SD

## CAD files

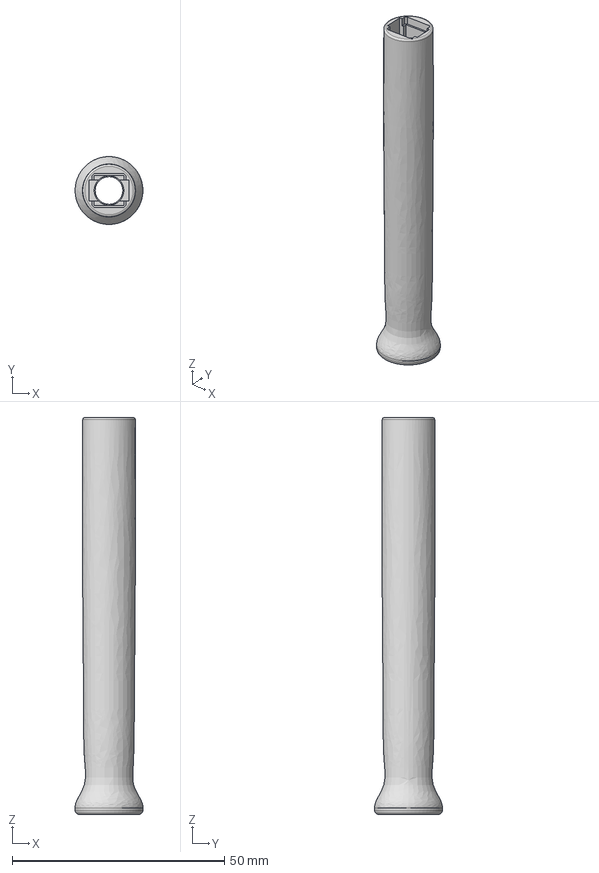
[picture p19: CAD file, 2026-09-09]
Handpiece/3D Printed Grip/RTSS Handpiece Smooth.step
16.0 x 16.0 x 93.6 mm

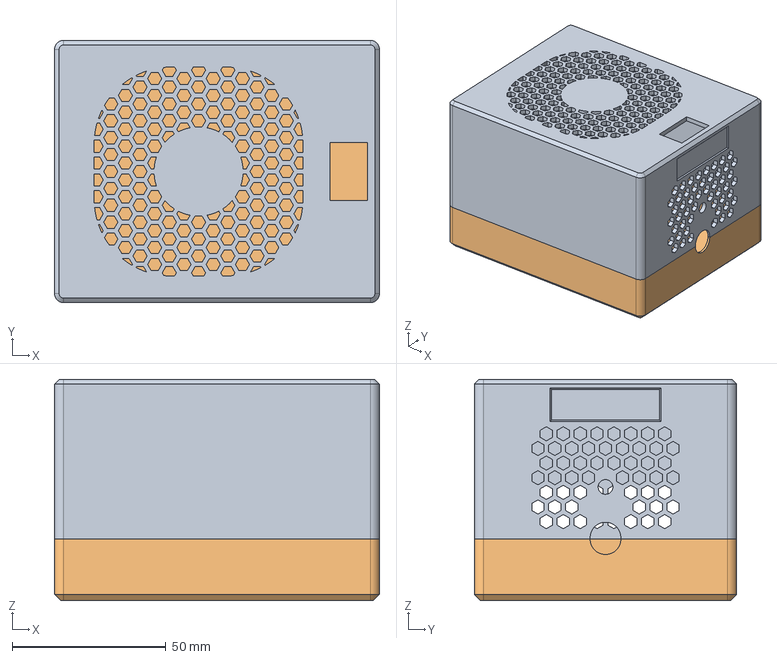
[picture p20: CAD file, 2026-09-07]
Power Supply/case/RTSS PS V2-5B PS case.step
105.8 x 85.4 x 72.0 mm

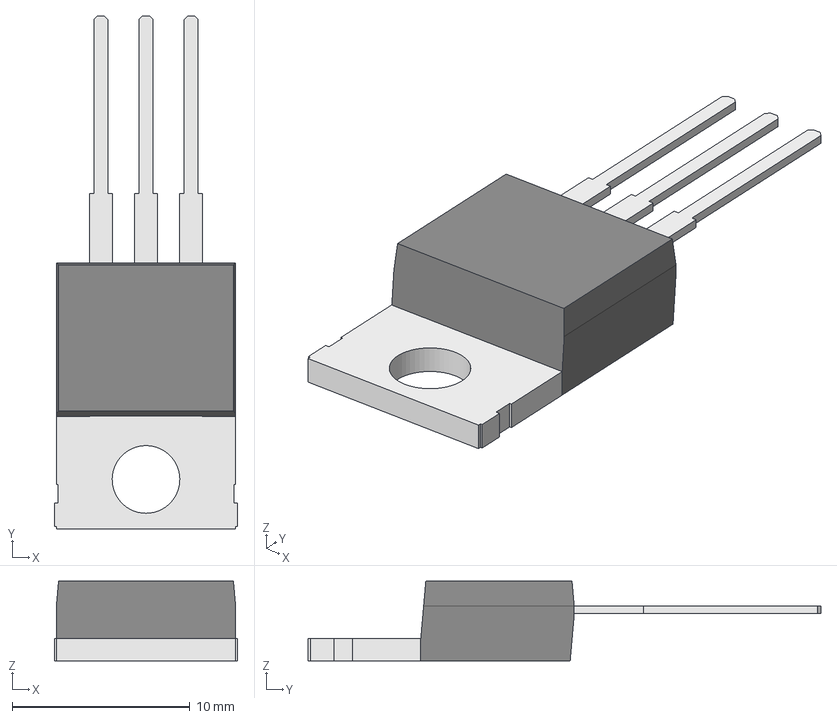
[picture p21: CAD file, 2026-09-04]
Power Supply/PCB/KiCad files/Custom_3D_models/to-220ac.stp
10.3 x 28.9 x 4.50 mm

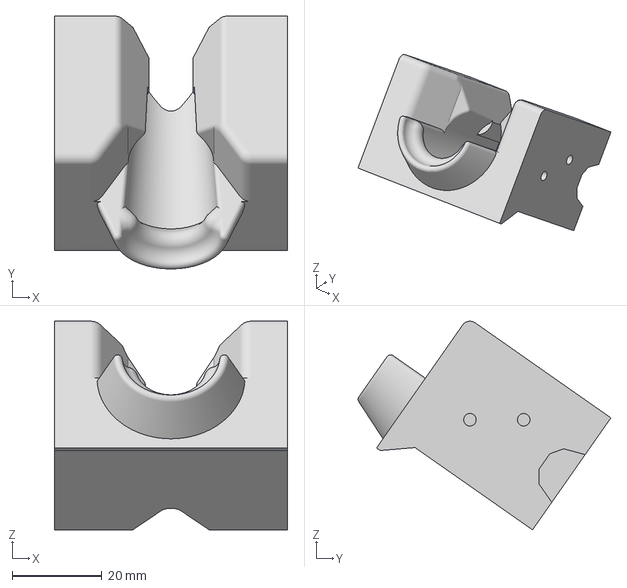
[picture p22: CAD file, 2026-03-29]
Workstand/3D_Printed_Parts/workstand insert.3mf
52.0 x 56.4 x 46.6 mm

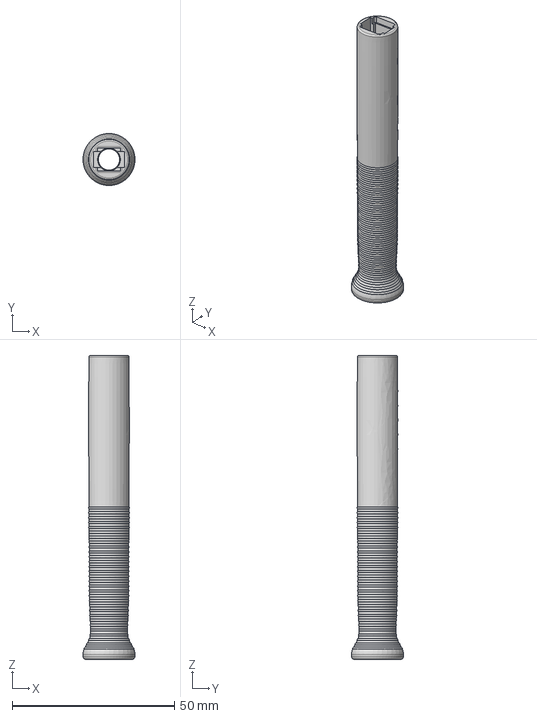
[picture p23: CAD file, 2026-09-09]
Handpiece/3D Printed Grip/RTSS Handpiece Ridges.step
16.0 x 16.0 x 93.6 mm

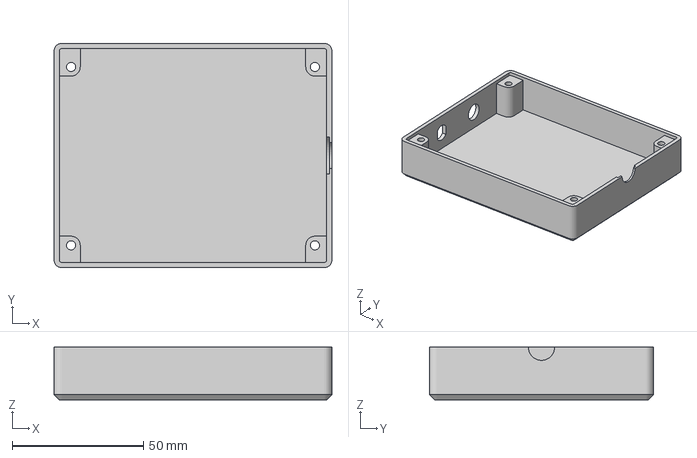
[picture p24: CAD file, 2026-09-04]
Power Supply/case/RTSS PS 2-5B PS case bottom.3mf
105.8 x 85.4 x 20.0 mm

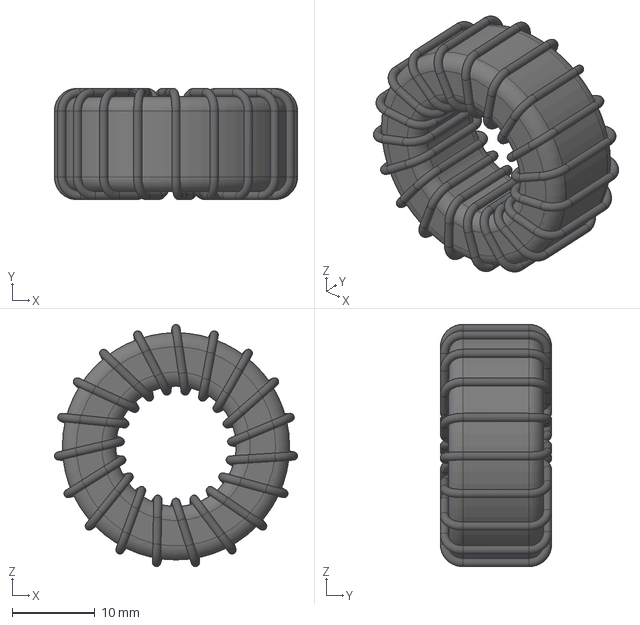
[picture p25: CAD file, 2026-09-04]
Power Supply/PCB/KiCad files/Custom_3D_models/koolmu core.step
29.3 x 13.4 x 29.2 mm

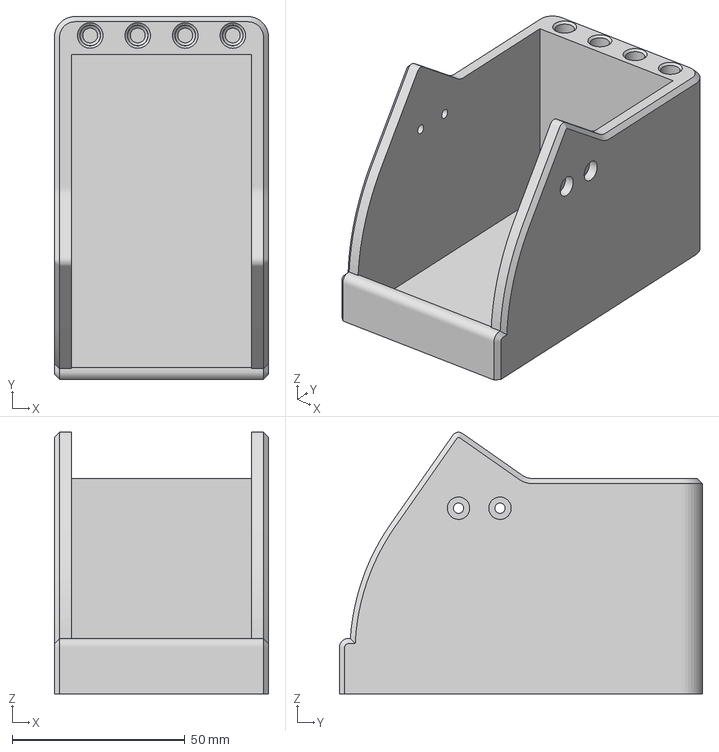
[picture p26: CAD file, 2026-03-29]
Workstand/3D_Printed_Parts/workstand base.3mf
62.0 x 105.0 x 75.7 mm

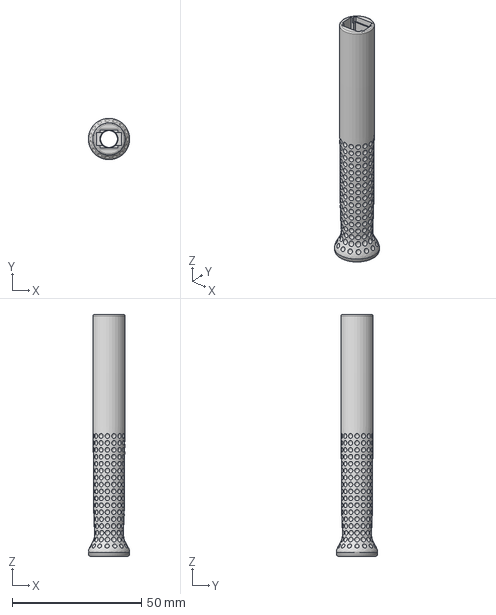
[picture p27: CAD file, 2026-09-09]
Handpiece/3D Printed Grip/RTSS Handpiece Dimples.step
16.0 x 16.0 x 93.6 mm

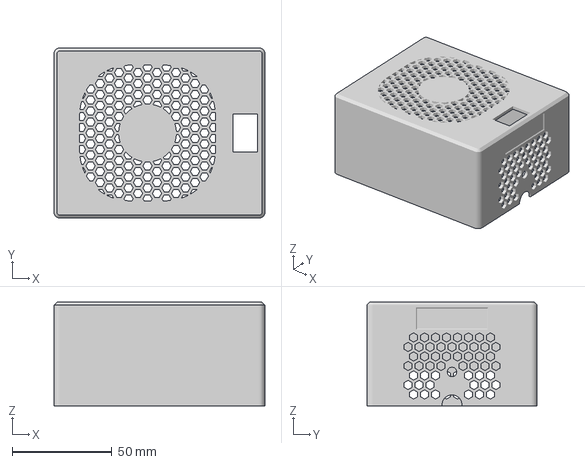
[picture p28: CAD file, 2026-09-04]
Power Supply/case/RTSS PS 2-5B PS case top.3mf
105.8 x 85.4 x 52.0 mm

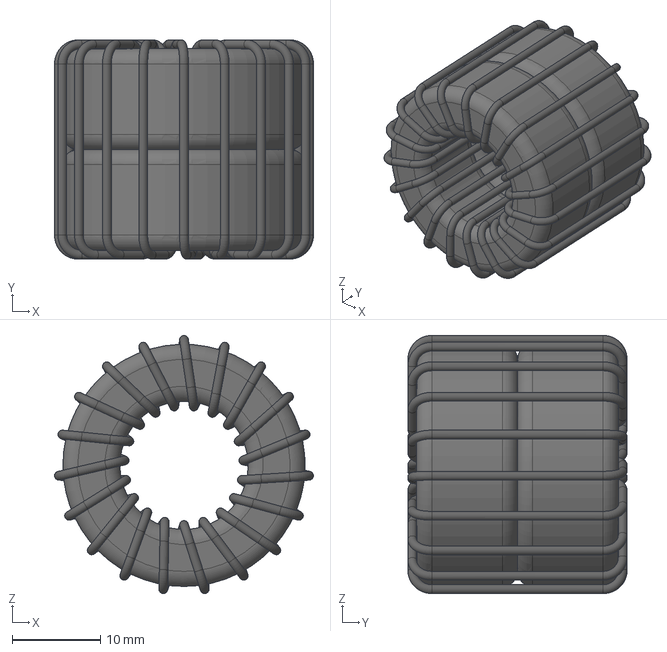
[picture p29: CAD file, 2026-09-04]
Power Supply/PCB/KiCad files/Custom_3D_models/koolmu core x2.step
29.3 x 24.8 x 29.2 mm

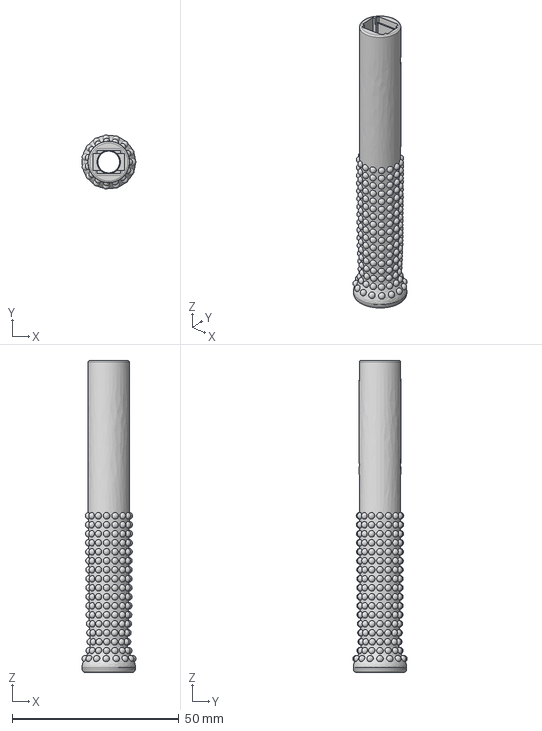
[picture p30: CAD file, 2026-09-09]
Handpiece/3D Printed Grip/RTSS Handpiece Bumps.step
16.2 x 16.3 x 93.6 mm

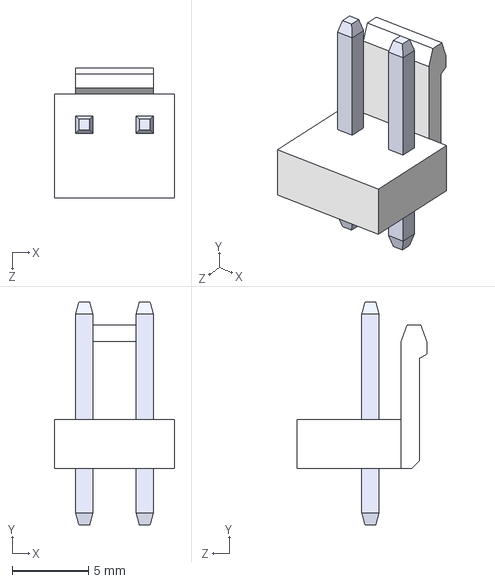
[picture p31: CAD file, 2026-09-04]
Power Supply/PCB/KiCad files/Custom_3D_models/B2P-VH.STEP
7.86 x 14.6 x 8.50 mm
BxP-VH_2
pin x 2

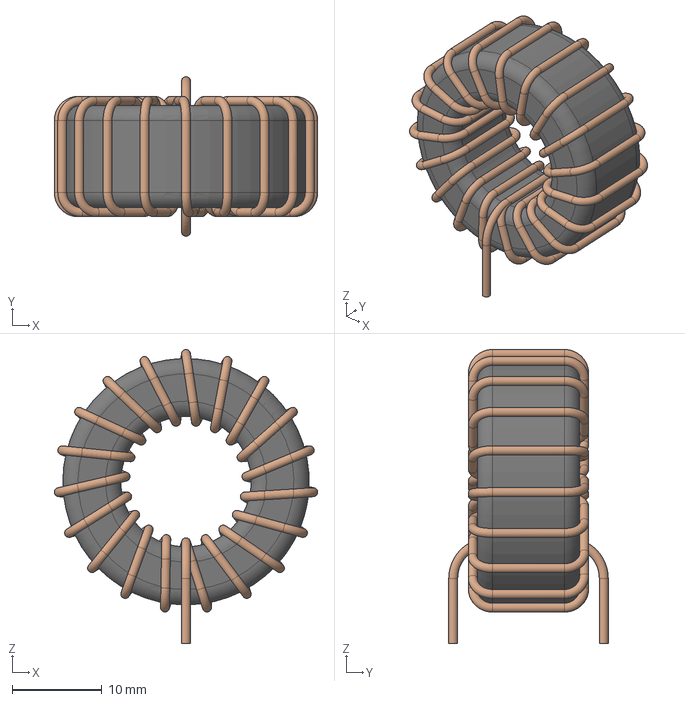
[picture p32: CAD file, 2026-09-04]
Power Supply/PCB/KiCad files/Custom_3D_models/koolmu core THT.step
29.3 x 17.7 x 32.7 mm

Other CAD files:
Handpiece/3D Printed Grip/RTSS Handpiece Shallow Ridges.3mf
Power Supply/PCB/KiCad files/Custom_3D_models/TO-220-3_Vertical_heatsink.step
Power Supply/PCB/KiCad files/Custom_3D_models/B2P-VH-LF--SN---3DModel-STEP-510211.STEP
Power Supply/PCB/KiCad files/Custom_3D_models/33uh inductor.step
Handpiece/3D Printed Grip/RTSS Handpiece Bumps.3mf
Handpiece/3D Printed Grip/RTSS Handpiece Dimples.3mf
Handpiece/3D Printed Grip/RTSS Handpiece Ridges.3mf
Handpiece/3D Printed Grip/RTSS Handpiece Smooth.3mf
Power Supply/PCB/KiCad files/Custom_3D_models/RTSS_Power_Supply_V2-5B.step

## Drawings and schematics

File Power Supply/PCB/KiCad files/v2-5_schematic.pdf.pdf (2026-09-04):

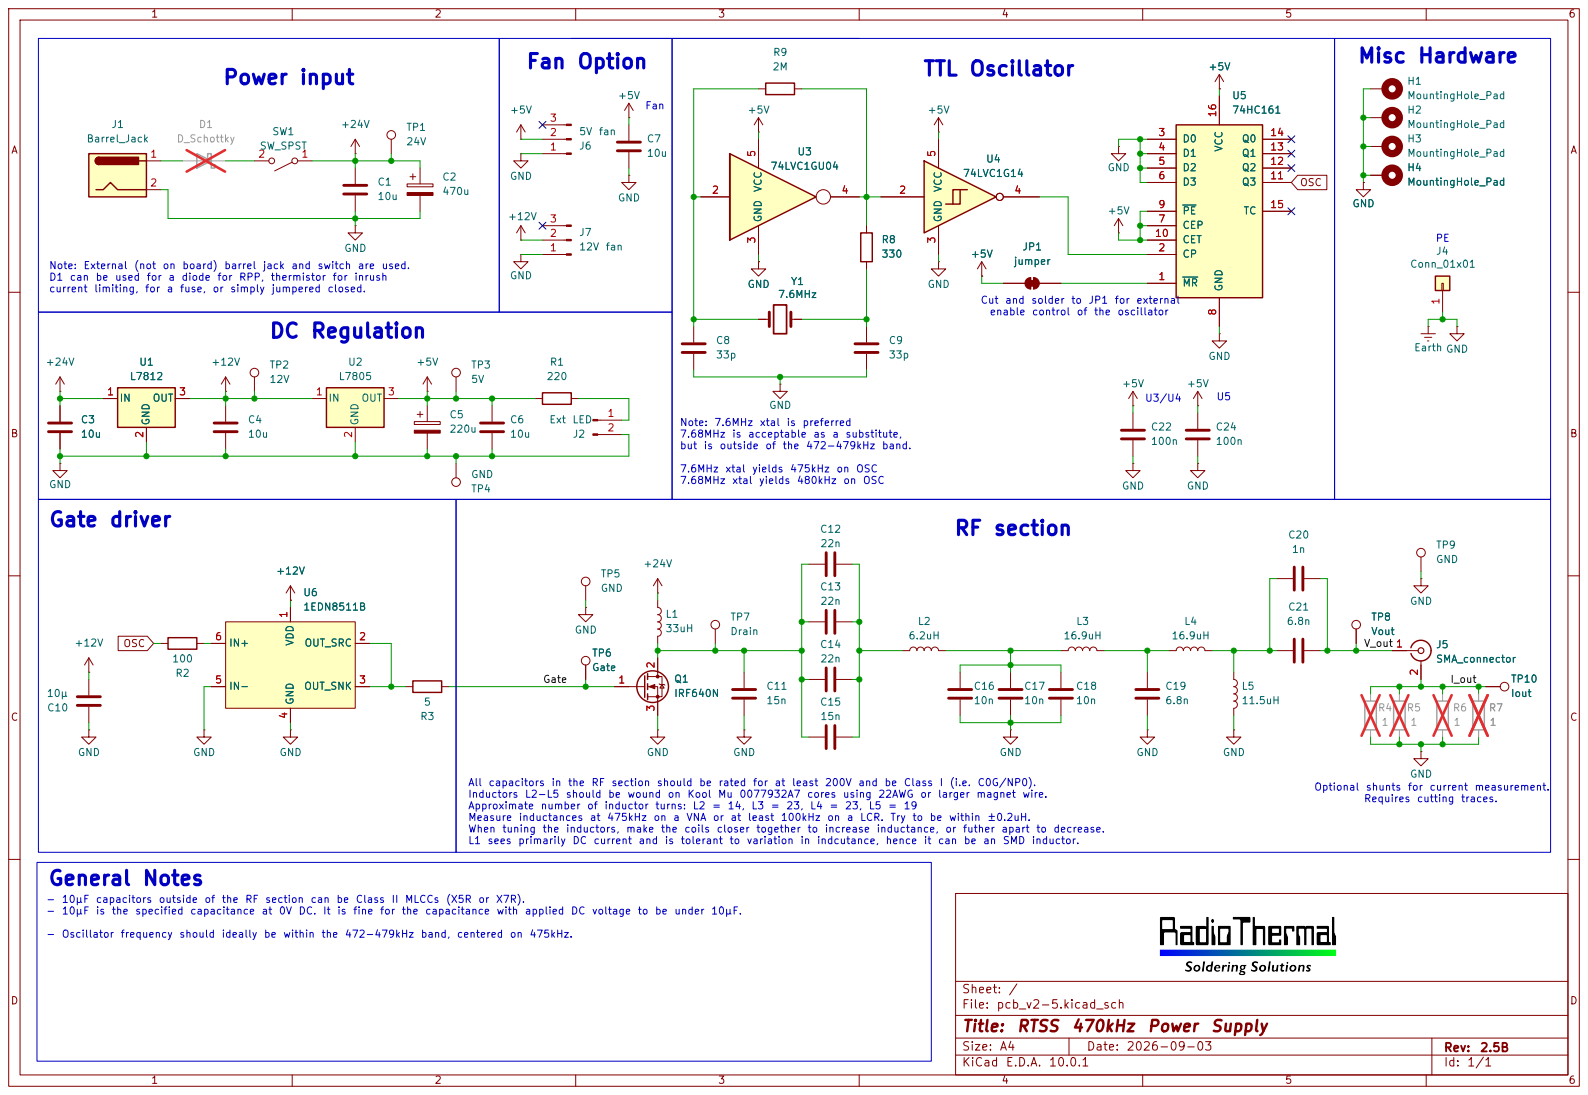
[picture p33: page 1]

Note: External (not on board) barrel jack and switch are used. D1 can be used for a diode for RPP, thermistor for inrush

Optional shunts for current measurement. Requires cutting traces. Cut and solder to JP1 for external enable control of the oscillator U3/U4

Sheet: /
File: pcb_v2-5.kicad_sch
Title: RTSS 470kHz Power Supply

Size: A4 | Rev: 2.5B
KiCad E.D.A. 10.0.1 | Id: 1/1

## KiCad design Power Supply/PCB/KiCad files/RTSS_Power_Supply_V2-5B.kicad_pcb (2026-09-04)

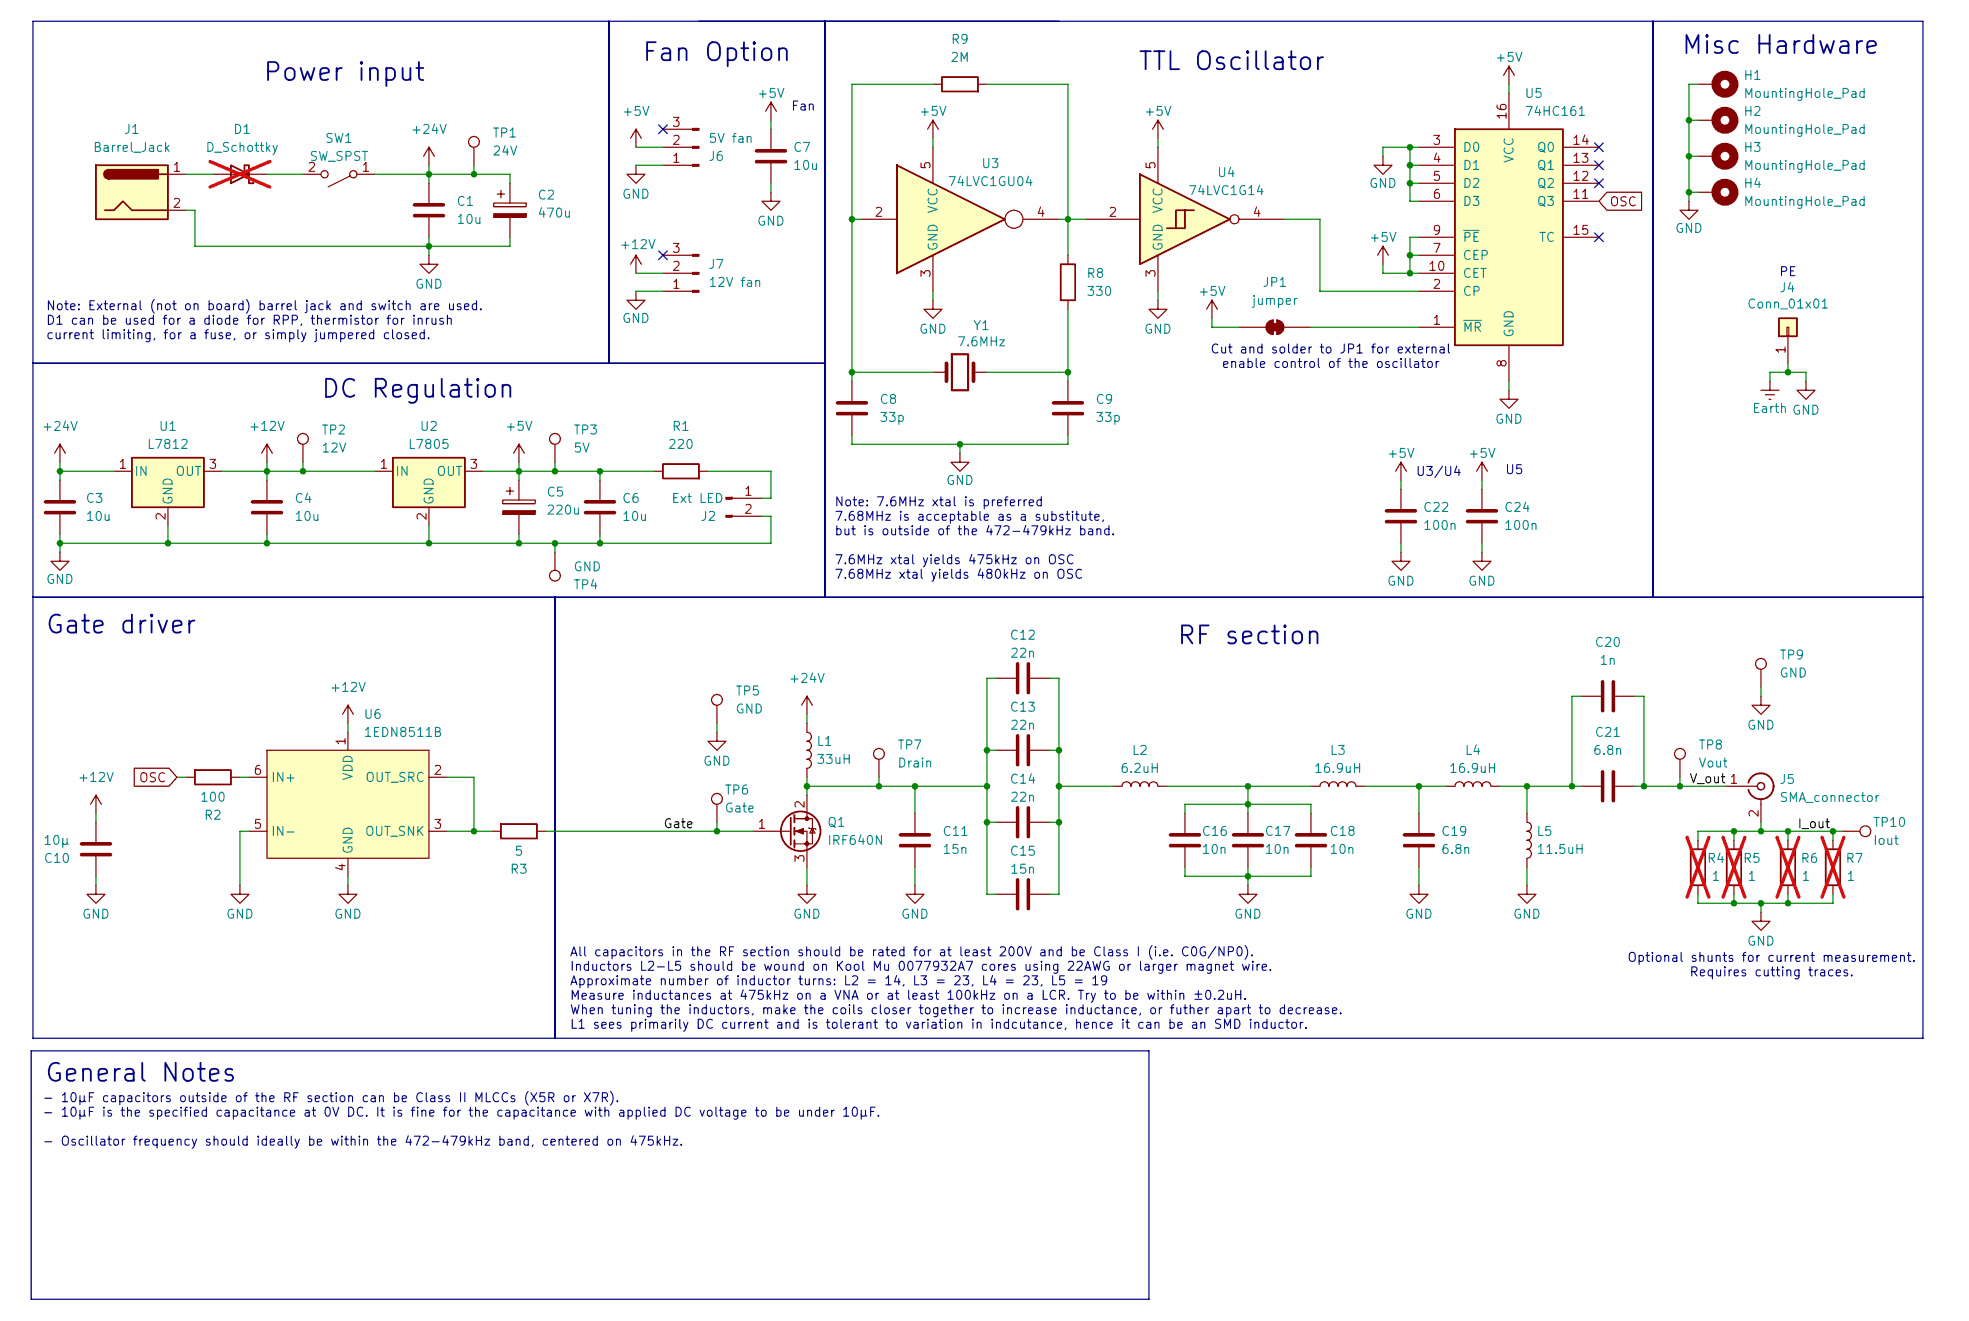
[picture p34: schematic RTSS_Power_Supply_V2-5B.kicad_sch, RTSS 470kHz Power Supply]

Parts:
C1, C3, C4, C6, C7: 10u; C_1206_3216Metric_Pad1.33x1.80mm_HandSolder
C2: 470u; CP_Radial_D10.0mm_P5.00mm_P7.50mm
C5: 220u; CP_Radial_D6.3mm_P2.50mm
C8, C9: 33p; C_0603_1608Metric
C10: 10µ; C_1206_3216Metric_Pad1.33x1.80mm_HandSolder
C11, C15: 15n; C_1210_3225Metric_Pad1.33x2.70mm_HandSolder
C12, C13, C14: 22n; C_1206_3216Metric_Pad1.33x1.80mm_HandSolder
C16, C17, C18: 10n; C_1206_3216Metric_Pad1.33x1.80mm_HandSolder
C19, C21: 6.8n; C_1210_3225Metric_Pad1.33x2.70mm_HandSolder
C20: 1n; C_1206_3216Metric_Pad1.33x1.80mm_HandSolder
C22, C24: 100n; C_0603_1608Metric
D1: D_Schottky; TO-220-2_Vertical; not fitted
H1, H2, H3, H4: MountingHole_Pad; MountingHole_3.2mm_M3_DIN965_Pad
J1: Barrel_Jack; 3D-JWT_A3963_1x02_P3.96mm_Vertical
J2: Ext LED; PinHeader_1x02_P2.54mm_Vertical
J4: Conn_01x01; SolderWire-1sqmm_1x01_D1.4mm_OD2.7mm
J5: SMA_connector; SMA_EdgeMount_Horizontal
J6: 5V fan; FanPinHeader_1x03_P2.54mm_Vertical
J7: 12V fan; FanPinHeader_1x03_P2.54mm_Vertical
JP1: jumper; SolderJumper-2_P1.3mm_Bridged_RoundedPad1.0x1.5mm
L1: 33uH; L_Pulse_PA4343
L2: 6.2uH; L_Koolmu_1x_small_THTonly_0077932A7
L3, L4: 16.9uH; L_Koolmu_1x_small_THTonly_0077932A7
L5: 11.5uH; L_Koolmu_1x_small_THTonly_0077932A7
Q1: IRF640N; 3D_TO-220-3_Vertical
R1: 220; C_0805_2012Metric_Pad1.18x1.45mm_HandSolder
R2: 100; R_0805_2012Metric
R3: 5; Bridge_R_0805_2012Metric
R4, R5, R6, R7: 1; Bridge_R_1206_3216Metric; not fitted
R8: 330; R_0805_2012Metric
R9: 2M; R_0805_2012Metric
SW1: SW_SPST; 3D-JWT_A3963_1x02_P3.96mm_Vertical
TP1: 24V; TestPoint_Plated_Hole_D2.0mm
TP2: 12V; TestPoint_Pad_D1.0mm
TP3: 5V; TestPoint_Pad_D1.0mm
TP4: GND; TestPoint_Pad_D1.0mm
TP5, TP9: GND; TestPoint_THTPad_2.0x2.0mm_Drill1.0mm
TP6: Gate; TestPoint_THTPad_2.0x2.0mm_Drill1.0mm
TP7: Drain; TestPoint_THTPad_2.0x2.0mm_Drill1.0mm
TP8: Vout; TestPoint_THTPad_2.0x2.0mm_Drill1.0mm
TP10: Iout; TestPoint_THTPad_2.0x2.0mm_Drill1.0mm
U1: L7812; TO-252-3_TabPin2
U2: L7805; TO-252-3_TabPin2
U3: 74LVC1GU04; SOT-553
U4: 74LVC1G14; SOT-553
U5: 74HC161; SOP-16_4.4x10.4mm_P1.27mm
U6: 1EDN8511B; SOT-23-6_Handsoldering
Y1: 7.6MHz; Crystal_SMD_HC49-SD

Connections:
+5V: C5.1, C6.1, C7.1, C22.1, C24.1, J6.2, JP1.1 (A), R1.1, TP3.1 (1_1), U2.3 (OUT), U3.5 (VCC), U4.5 (VCC), U5.7 (CEP), U5.9 (~PE), U5.10 (CET), U5.16 (VCC)
+12V: C4.1, C10.2, J7.2, TP2.1 (1_1), U1.3 (OUT), U2.1 (IN), U6.1 (VDD)
+24V: C1.1, C2.1, C3.1, L1.1, SW1.1 (A), TP1.1 (1_1), U1.1 (IN)
/Gate: Q1.1 (G), R3.1, TP6.1 (1_1)
/I_out: J5.2 (Ext), R4.1, R5.1, R6.1, R7.1, TP10.1 (1_1)
/V_out: C20.2, C21.2, J5.1 (In), TP8.1 (1_1)
Earth: C1.2, C2.2, C3.2, C4.2, C5.2, C6.2, C7.2, C8.2, C9.2, C10.1, C11.2, C16.2, C17.2, C18.2, C19.2, C22.2, C24.2, H1.1 (1_1), H2.1 (1_1), H3.1 (1_1), H4.1 (1_1), J1.2, J2.2, J4.1 (Pin_1_1), J6.1, J7.1, L5.2, Q1.3 (S), R4.2, R5.2, R6.2, R7.2, TP4.1 (1_1), TP5.1 (1_1), TP9.1 (1_1), U1.2 (GND), U2.2 (GND), U3.3 (GND), U4.3 (GND), U5.3 (D0), U5.4 (D1), U5.5 (D2), U5.6 (D3), U5.8 (GND), U6.4 (GND), U6.5 (IN-)
unnamed: C8.1, R9.1, U3.2, Y1.1
unnamed: C9.1, R8.2, Y1.2
unnamed: C12.2, C13.2, C14.2, C15.2, L2.1
unnamed: C16.1, C17.1, C18.1, L2.2, L3.1
unnamed: C19.1, L3.2, L4.1
unnamed: C20.1, C21.1, L4.2, L5.1
unnamed: D1.2 (A), J1.1
unnamed: D1.1 (K), SW1.2 (B)
unnamed: J2.1, R1.2
unnamed: JP1.2 (B), U5.1 (~MR)
unnamed: C11.1, C12.1, C13.1, C14.1, C15.1, L1.2, Q1.2 (D), TP7.1 (1_1)
unnamed: R8.1, R9.2, U3.4, U4.2
unnamed: U4.4, U5.2 (CP)
unnamed: R2.1, U6.6 (IN+)
unnamed: R3.2, U6.2 (OUT_SRC), U6.3 (OUT_SNK)
OSC: R2.2, U5.11 (Q3)

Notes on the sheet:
RF section
Note: 7.6MHz xtal is preferred 7.68MHz is acceptable as a substitute, but is outside of the 472-479kHz band. 7.6MHz xtal yields 475kHz on OSC 7.68MHz xtal yields 480kHz on OSC
Cut and solder to JP1 for external enable control of the oscillator
Gate driver
All capacitors in the RF section should be rated for at least 200V and be Class I (i.e. C0G/NP0). Inductors L2-L5 should be wound on Kool Mu 0077932A7 cores using 22AWG or larger magnet wire. Approximate number of inductor turns: L2 = 14, L3 = 23, L4 = 23, L5 = 19 Measure inductances at 475kHz on a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
Power input
Misc Hardware
TTL Oscillator
Fan Option
U3/U4
General Notes
Note: External (not on board) barrel jack and switch are used. D1 can be used for a diode for RPP, thermistor for inrush current limiting, for a fuse, or simply jumpered closed.
- 10µF capacitors outside of the RF section can be Class II MLCCs (X5R or X7R). - 10µF is the specified capacitance at 0V DC. It is fine for the capacitance with applied DC voltage to be under 10µF. - Oscillator frequency should ideally be within the 472-479kHz band, centered on 475kHz.
Optional shunts for current measurement. Requires cutting traces.
Fan
DC Regulation

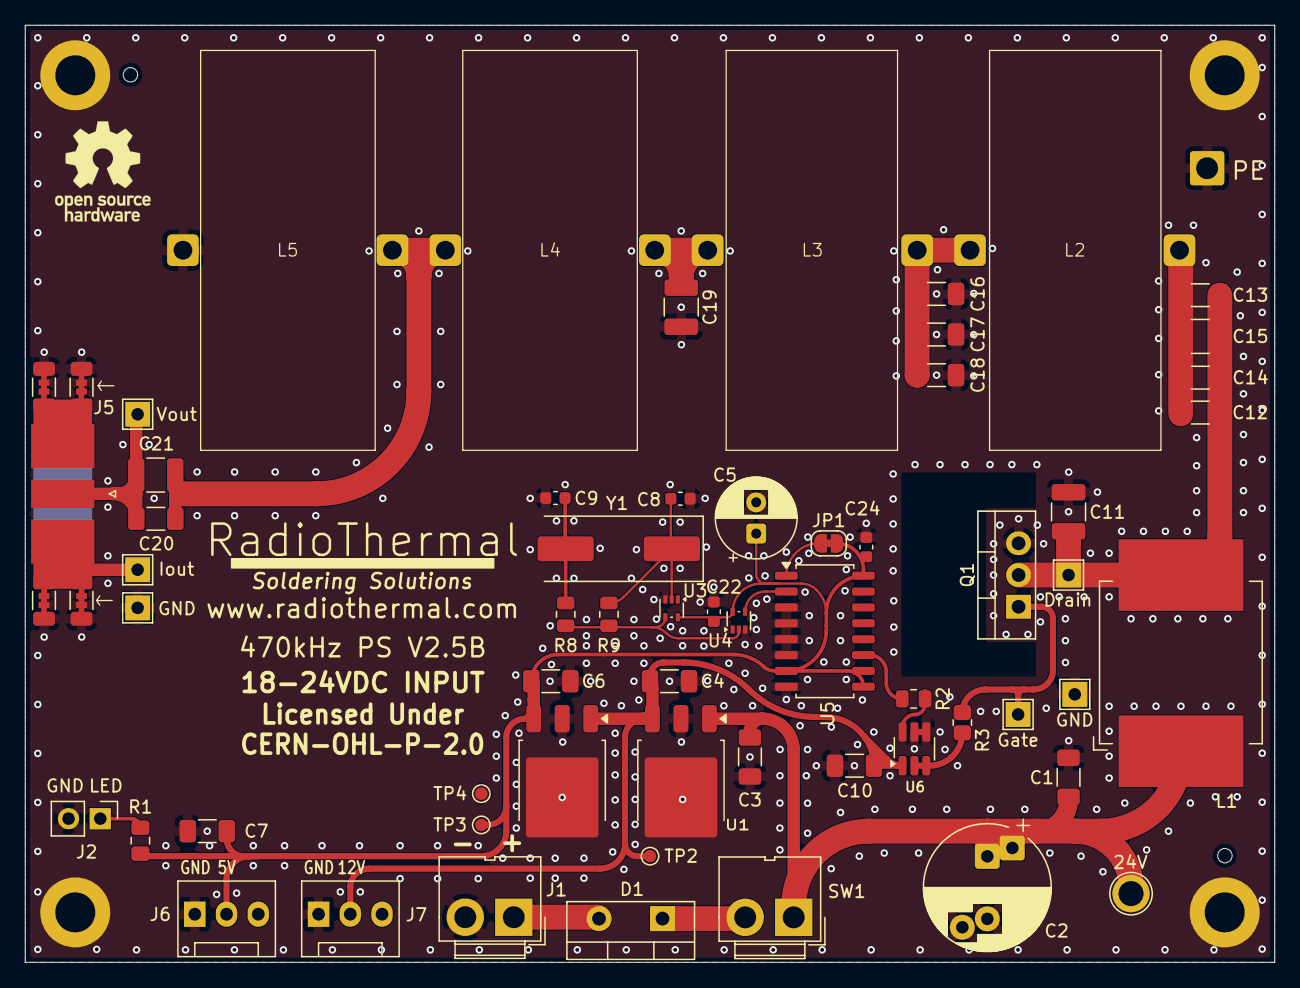
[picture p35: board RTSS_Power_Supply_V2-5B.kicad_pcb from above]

Board: 2 copper layers, 100.0 x 75.0 mm, 68 parts (0 on the bottom side), 23 nets.

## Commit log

2025-07-18 added initial release files
    [470KHz_Bumps.3mf, 470KHz_Deep_Ridges.3mf, 470KHz_Dimples.3mf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]
2026-03-16 Added PCB design and adapter schematic
    [RTSS_PS_PCB2_3B1.kicad_pcb, RTSS_PS_PCB2_3B1.kicad_sch, RTSS_PS_PCB2_3B1.step]
2026-03-16 updated readme for Power Supplyt
2026-03-29 Updated workstand design and added photos
    [workstand base.3mf, workstand insert.3mf]
2026-04-04 Added power supply case design
    workstand instructions added and DIN adapter image fixed
    [RTSS 2.3B1 PS case bottom.3mf, RTSS 2.3B1 PS case top.3mf]
2026-07-12 Update readme.md
    Updated and added info for multiple connector types.
2026-09-04 Release Power Supply V2.5B
    In version 2.5B of the PCB, we have made a few improvements to reduce cost and increase reliability compared with version 2.3B1. Most notably the oscillator section has been redesigned to eliminate the need for a microcontroller and now only relies on a 7.6MHz crystal oscillator and TTL logic. To reduce costs, we have eliminated the daughterboard by moving everything onto the main board, additionally L2 has been updated to only use a single inductor core from the two cores required on previous versions. Moving all of this new hardware onto the main board has had the consequence of causing us to remove the TO-247 MOSFET option in favor of TO-220 to save space.
    [33uh inductor.step, B2P-VH-LF--SN---3DModel-STEP-510211.STEP, B2P-VH.STEP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]
2026-09-04 Fix schematic in readme
    Updated schematic image reference.
2026-09-04 add background color to schematic
2026-09-07 add STEP model for power supply case
    [RTSS PS V2-5B PS case.step]
2026-09-09 Add STEP versions of handpiece grips
    [RTSS Handpiece Bumps.3mf, RTSS Handpiece Bumps.step, RTSS Handpiece Dimples.3mf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]
2026-09-29 Add digikey BOM for V2.5B
    Updated readme.md for version 2.5B with improved clarity and links.
2026-10-08 Add alternate crown spring sources and fix typos
2026-10-08 Add Kicad files and gerbers for Handpiece PCB
    [470K_handpiece_PCB.kicad_pcb]
2026-10-08 Update instruction for use with Handpiece PCB option
2026-10-11 Create contributing.md
    Explicitly ban AI contributions and add basic guidelines for PCB design changes
2026-10-11 Fix typos in Cable readme.md
2026-10-19 Update PCB to V2.5C
    Changed reference designators for continuity and updated Digikey BOMs

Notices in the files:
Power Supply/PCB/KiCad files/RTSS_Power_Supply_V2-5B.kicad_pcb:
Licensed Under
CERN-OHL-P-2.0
